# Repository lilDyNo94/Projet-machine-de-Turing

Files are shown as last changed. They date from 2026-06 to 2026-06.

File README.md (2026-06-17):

# 💻 Projet Électronique - Machine de Turing

**Auteurs :** Dylan Deshauteurs & Samba Niang  
**Encadrant :** M. Ronan Bocquillon 

---

## 📂 Arborescence du dépôt

Voici comment est structuré notre dépôt :

```text
.
├── Archive/                                  # Historique des projets des années précédentes
│   ├── Projet_2022_2023/
│   ├── Projet_2023_2024/
│   └── Projet_2024_2025/
│
├── Projet Elec - Machine de Turing/          # Dossier principal 
│   ├── Code/                                 # Fichiers sources et scripts annexes
│   ├── Datasheets/                           # Documentations techniques des composants électroniques
│   ├── KiCad/
│   │   └── Machine_de_turing/                # Fichiers de conception du routage PCB
│   ├── Ressources/                           # Images et ressources documentaires
│   ├── Schéma_élec/                          # Schémas structurels du circuit
│   ├── Diapo_Présentation_Machine_de_Turing_DESHAUTEURS_NIANG.pdf  # Support de présentation
│   └── Rapport_Machine_de_Turing_Deshauteurs_Niang.pdf             # Compte-rendu final du projet
│
├── lib_turing.c                              # Code source des fonctions de la Machine de Turing
├── lib_turing.h                              # Fichier d'en-tête (prototypes et structures)
├── main.c                                    # Programme principal (logique algorithmique)
└── README.md

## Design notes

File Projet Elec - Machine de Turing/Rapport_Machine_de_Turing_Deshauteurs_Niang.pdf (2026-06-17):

# P R O J E T E L E C T R O N I Q U E

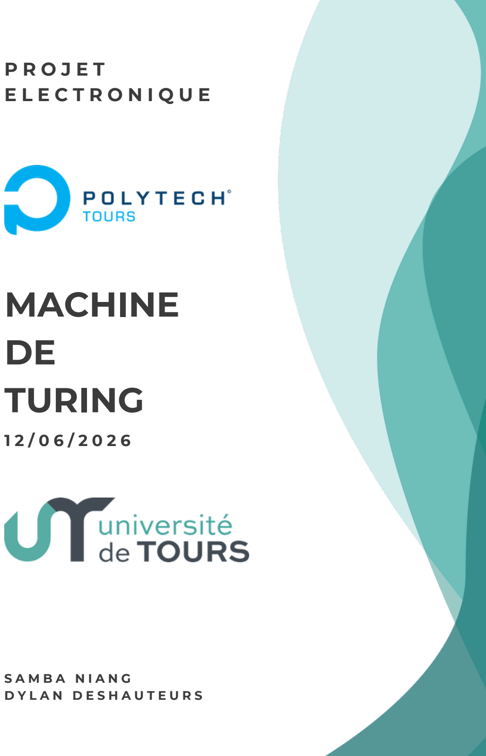
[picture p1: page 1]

# MACHINE

DE

# TURING

## D Y L A N D E S H A U T E U R S

1 2 / 0 6 / 2 0 2 6

## S A M B A N I A N G

SAMBA NIANG & DYLAN DESHAUTEURS | 0

## Sommaire

## I. Introduction

### Fondements Historiques

En 1936, le mathématicien britannique Alan Turing pose la pierre angulaire de l’informatique moderne avec son article « On Computable Numbers ». Loin des préoccupations matérielles de l'époque, Turing mène une réflexion de logique pure pour définir l'essence même du calcul.

Il conçoit alors une machine universelle théorique : un concept révolutionnaire capable d’exécuter n’importe quel processus logique, pourvu qu’il soit programmable.

Cette intuition théorique trouve son application concrète dès le déclenchement de la Seconde Guerre mondiale. Turing met ses concepts au service du décryptage pour briser les codes de la machine allemande Enigma.

### La Machine de Turing Universelle (MTU)

Le concept de Turing repose se compose de quatre éléments :

- Le Ruban : Une mémoire potentiellement infinie divisée en cases, chacune contenant un symbole.
- La Tête de Lecture/Écriture : Un dispositif capable de lire le symbole d'une case, d'en écrire un nouveau et de se déplacer vers la gauche ou la droite.
- Le Registre d'État : Il stocke l'état interne de la machine à un instant T.
- La Table de Transition : Il constitue le programme de la machine. Elle définit les règles d'interaction entre les trois composants précédents.

Le fonctionnement repose sur une table de transition. Pour chaque configuration (État actuel, Symbole lu), la machine exécute une action selon une règle stricte :

1. Écrire un nouveau symbole dans la case.
2. Changer l'état interne de la machine.
3. Déplacer la tête de lecture (Gauche/Droite/Immobile).

Exemple de transition : Si la machine est à l'état "E1" et lit "0", elle écrit "1", passe à l'état "E2" et se déplace vers la droite.

## II. Contexte Académique & états des lieux

Dans le cadre du cursus Informatique et Systèmes Intelligents Embarqués (ISIE), ce projet vise à transcrire les concepts abstraits de Turing en une réalisation concrète, aboutissant à la création d'une Machine de Turing Électronique.

### Continuité pédagogique

Cinquième équipe à relever ce défi, notre mission s'inscrit dans une véritable continuité pédagogique. L'enjeu est de consolider les acquis des groupes précédents pour aboutir à une version finale aboutie et stabilisée. Pour ce faire, notre développement s'appuie principalement sur l'architecture de ALLEGRE-COMMINGES Clément et BROUARD Romain, tout en intégrant les optimisations apportées par l'équipe de BOLARD Yassine et MANSO Alexis.

### Synthèse des travaux antérieurs

Le développement du projet a suivi une courbe d'apprentissage rigoureuse, partant de la conception théorique vers la mise en œuvre technique. Les premières recherches des groupes précédents ont permis de poser un socle fonctionnel solide.

L'effort s'est porté sur la production du firmware et l'assemblage des premiers composants. Toutefois, la réalisation finale a été freinée par des aléas matériels notamment des défaillances sur le ruban LED et par la complexité de l'intégration globale.

Ce passif technique nous permet aujourd'hui d'identifier précisément les points critiques, tant sur la fiabilité des composants que sur la gestion du temps, pour mener à bien l'achèvement de la maquette physique.

À notre arrivée, nous héritons d'une analyse théorique solide. Le projet se trouvait toutefois inachevé. Notre mission est d'agir comme intégrateur final : diagnostiquer les défaillances matérielles, corriger les erreurs de conception électronique et finaliser l'assemblage pour livrer une maquette 100% opérationnelle.

## III. Objectifs du Projet (Cahier des charges)

L’objectif principal est la conception et la réalisation d’un prototype physique fonctionnel d'une Machine de Turing Électronique, capable d'exécuter des processus logiques programmables.

### Phase 1 : Étude Théorique et Formalisation

L'enjeu est de maîtriser les fondements logiques avant toute implémentation technique :

1. Définir les principes de la machine de Turing et son architecture logique (Ruban, Tête, Table de transition).
2. Étudier et formaliser les algorithmes de calcul associés.
3. Présenter et expliciter un cas d'usage simple (exemple : incrémentation binaire) pour valider la compréhension du modèle.

### Phase 2 : Audit et Reprise de l'Existant

Afin de capitaliser sur les travaux des années précédentes, cette phase de "rétro-ingénierie" est cruciale :

1. Étudier les rapports existants pour en extraire les solutions les plus robustes.
2. Fixer l'architecture cible
3. Établir la nomenclature des composants et lancer les commandes.

### Phase 3 : Développement et Intégration Matérielle

Cette étape constitue le cœur technique de la réalisation :

1. Valider les schémas électroniques via des tests sur platine d'essai (Breadboard).
2. Adapter et implémenter le firmware en veillant à la stricte correspondance entre l'algorithme théorique et le déroulement du code.
3. Vérifier la fiabilité des cycles de lecture/écriture et des déplacements d'états.

### Phase bonus : Packaging et Conception CAO

Afin d'aboutir à un produit fini et professionnel :

1. Réaliser un circuit imprimé (PCB).
2. Concevoir et fabriquer un boîtier pour protéger l’électronique.

La planification complète de ces différentes étapes est synthétisée au sein d'une feuille de route globale, disponible en Annexe.

## IV. Analyse fonctionnelle

### Définition des besoins

Bête à corne

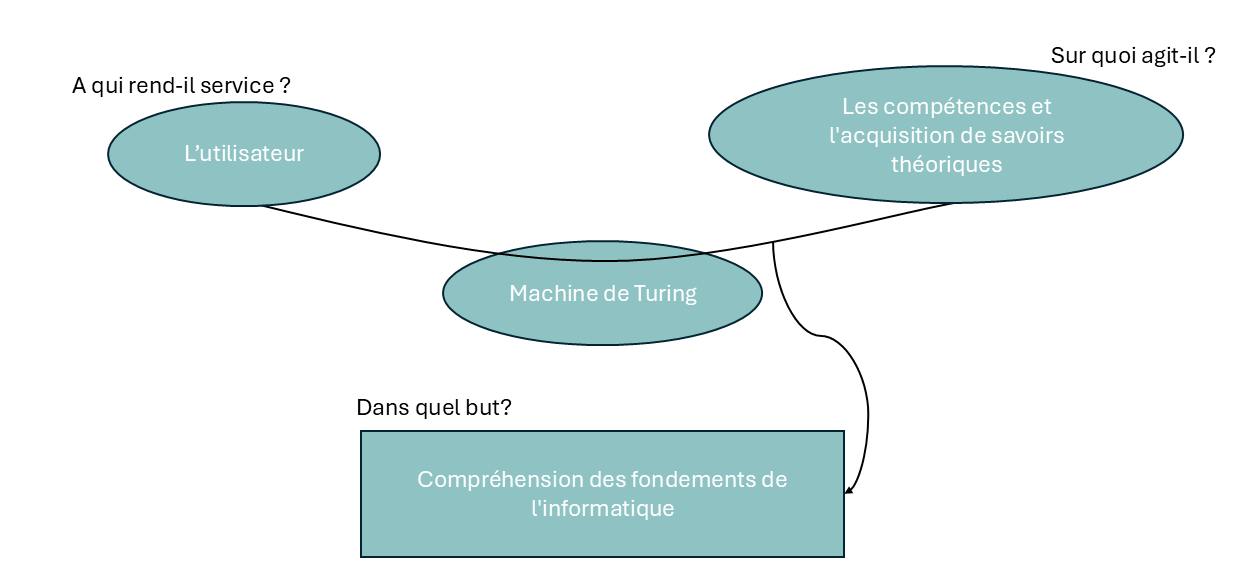
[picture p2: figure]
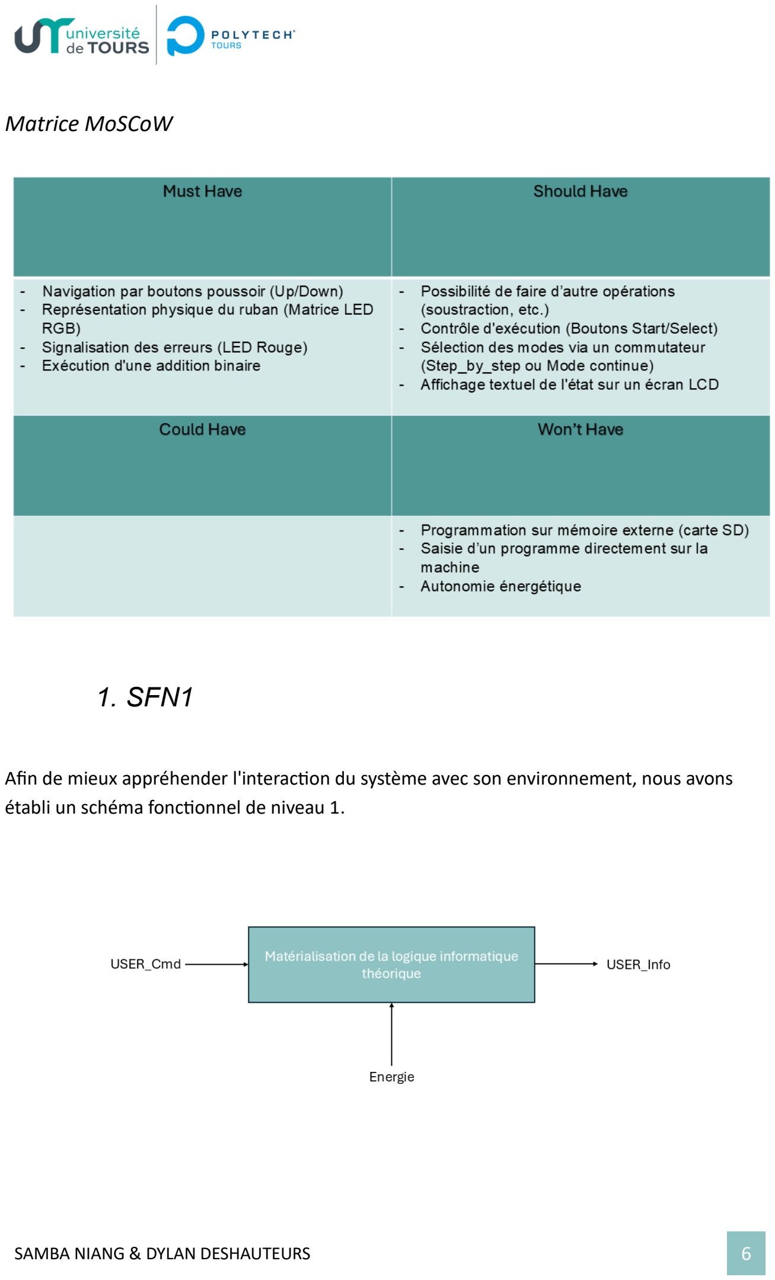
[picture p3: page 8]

Matrice MoSCoW

### 1. SFN1

Afin de mieux appréhender l'interaction du système avec son environnement, nous avons établi un schéma fonctionnel de niveau 1.

Les Commandes Utilisateur (boutons, commutateurs) pilotent la logique de la machine.

L'Énergie est fournie par le module d'alimentation stabilisé (3,3V/5V) pour permettre le fonctionnement des composants actifs.

Le bloc Traitement de la donnée est assuré par le microcontrôleur PIC24, qui exécute les règles de transition.

Le Résultat se traduit par la mise à jour visuelle du ruban LED et de l'écran LCD.

### 2. SF1D

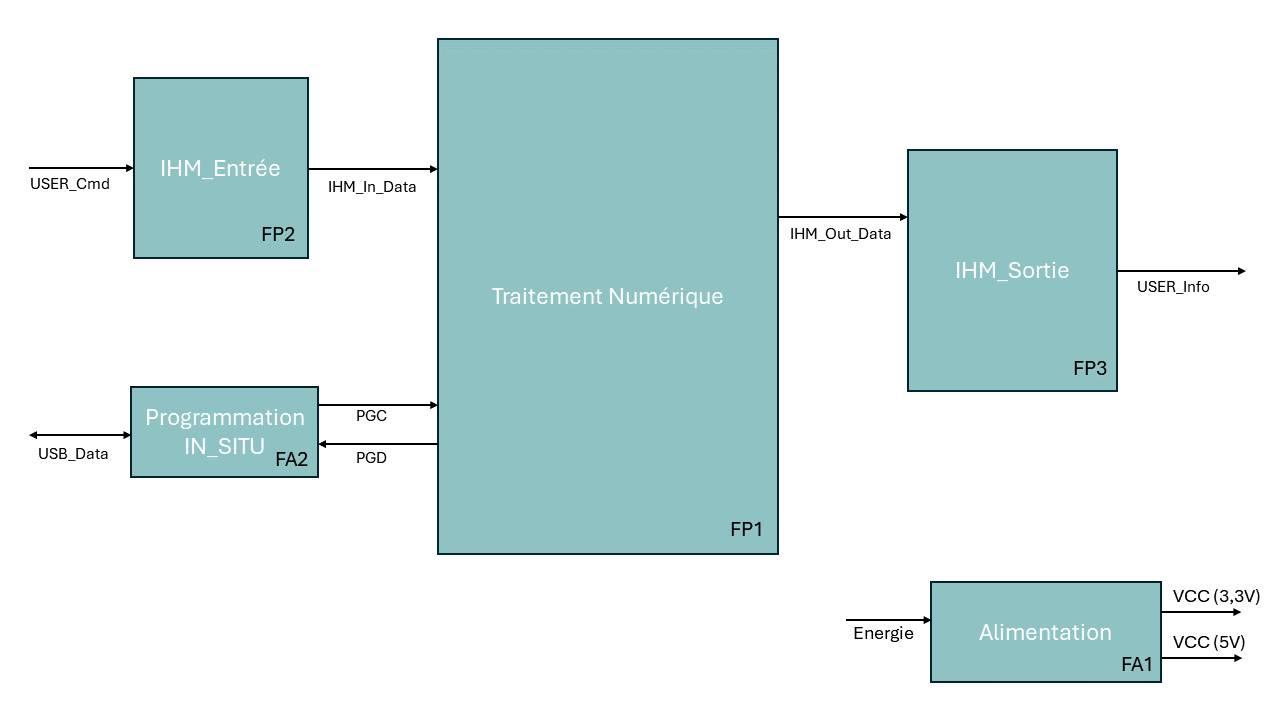
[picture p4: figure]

### 3. SF2D – FP2 (IHM_Entrée)

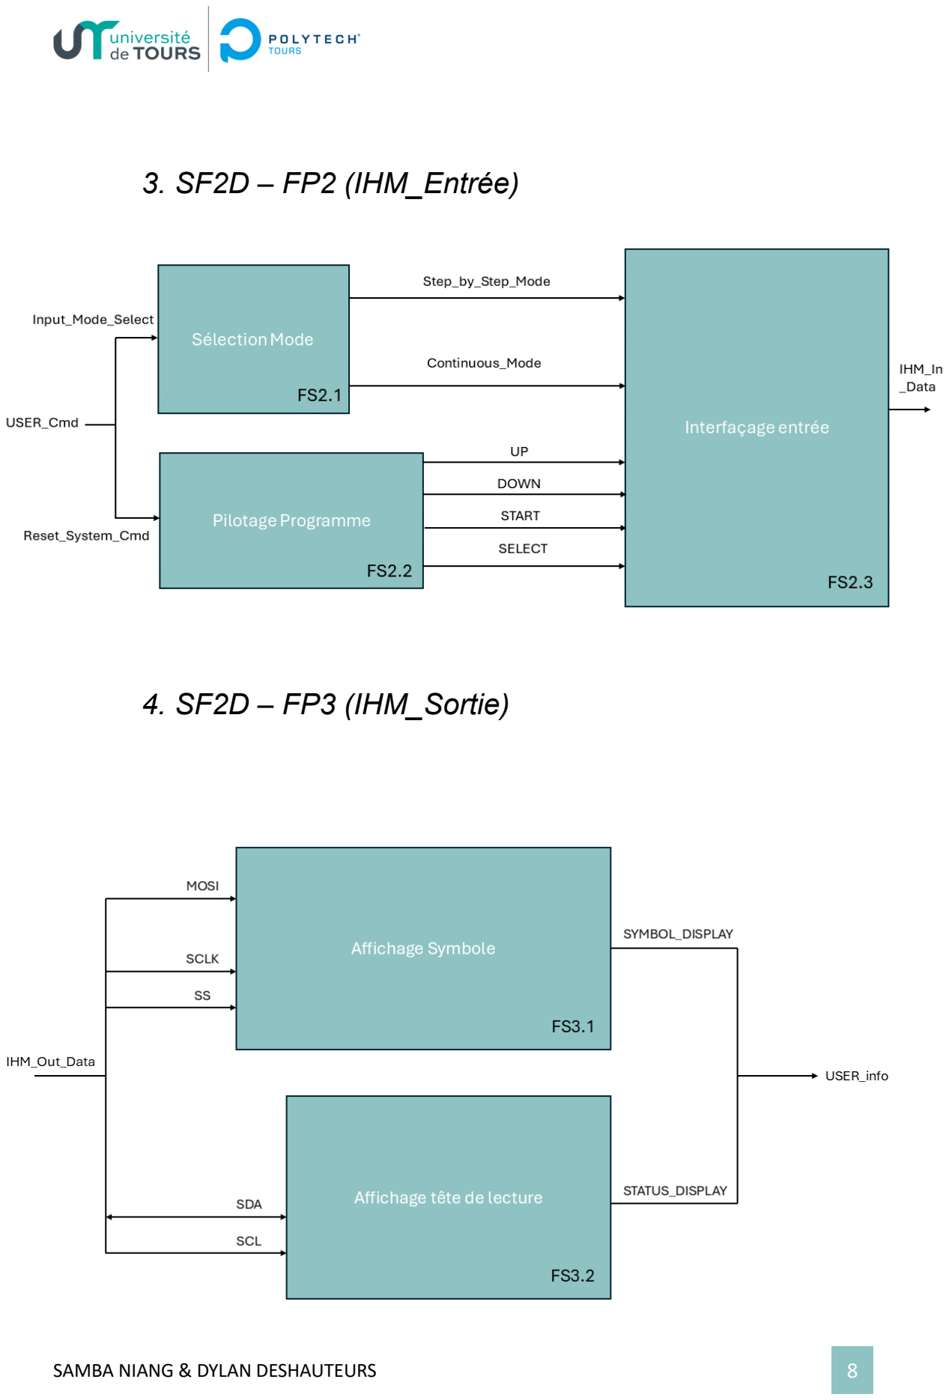
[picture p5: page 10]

### 4. SF2D – FP3 (IHM_Sortie)

### Spécifications des fonctions et de leurs signaux de communication

Fonction | FP1 | Traitements Numériques
Description / rôle | Réalise tous les traitements numériques nécessaires au bon fonctionnement du système
Signaux d'entrée | IHM_In_Data, IHM_Out_Data
Signaux de sortie | IHM_In_Ack, IHM_Out_St
Signaux E/S | Prog_Data
Fonction | FS 2.1 | Sélection mode
Description / rôle | Fonction qui sert à sélectionner le mode d’exécution pas à pas ou continu
Signaux d'entrée | Input_Mode_Select
Signaux de sortie | Step_by_Step_Mode, Continuous_Mode
Signaux E/S | NA
Fonction | FS 2.2 | Initialisation du programme
Description / rôle | Fonction qui permet d’initialiser les symboles et la tête de lecture
Signaux d'entrée | Reset_System_Cmd
Signaux de sortie | Start, Up, Down, Select
Signaux E/S | NA

Fonction | FS 2.3 | Interfaçage d’entrée
Description / rôle | Fonction qui sert de réceptacle et de commande du MCU
Signaux d'entrée | Start, Up, Down, Select, Step_by_Step_Mode, Continuous_Mode
Signaux de sortie | SCL
Signaux E/S | SDA
Fonction | FS 3.1 | Affichage Symbole
Description / rôle | Fonction réalisant l’affichage des symboles
Signaux d'entrée | MOSI, SCLK, SS
Signaux de sortie | MISO, Symbol_Display
Signaux E/S | NA
Fonction | FS 3.2 | Affichage de tête de lecture
Description / rôle | Fonction réalisant l’affichage de la tête de lecture
Signaux d'entrée | MOSI, SCLK, SS
Signaux de sortie | MISO, Status_Display
Signaux E/S | NA

Fonction | FA 1 | Alimentation
Description / rôle | Fonction qui alimente le système en électricité
Signaux d'entrée | Energie
Signaux de sortie | VCC
Signaux E/S | NA
Fonction | FA 2 | Programmation In Situ
Description / rôle | Fonction permettant de charger le programme dans le MCU
Signaux d'entrée | NA
Signaux de sortie | NA
Signaux E/S | USB_Data, Prog_Data

Ce tableau détaille l'ensemble des caractéristiques physiques, électriques et logiques de tous les signaux du système.

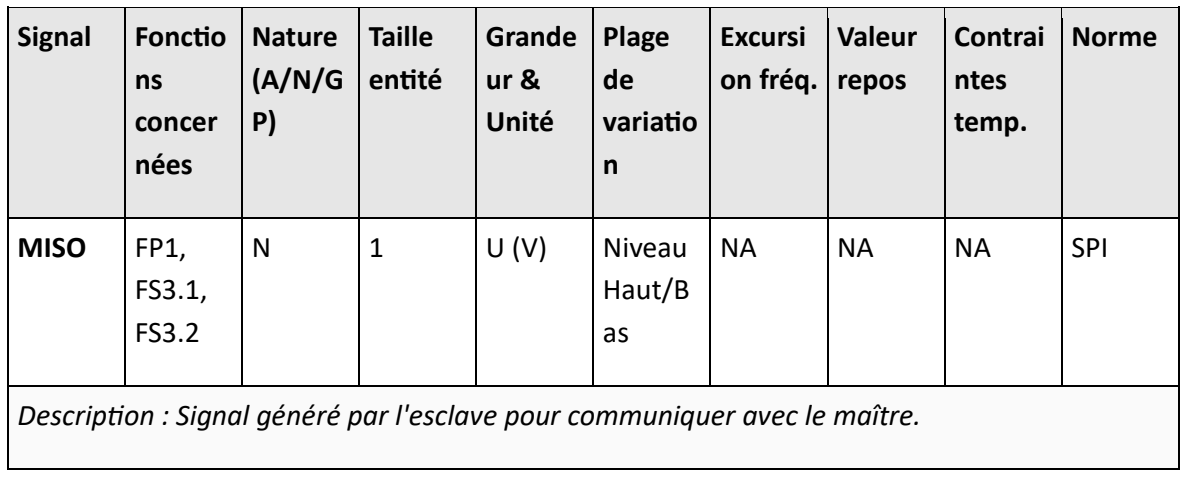
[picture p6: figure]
Signal; Fonctio; ns concer nées; Nature (A/N/G P); Taille entité; Grande ur & Unité; Plage de variatio n; Excursi on fréq.; Valeur repos; Contrai ntes temp.; Norme; MISO; Niveau; Haut/B as; SPI

Description : Signal généré par l'esclave pour communiquer avec le maître.

Signal Fonctio ns concer nées

Nature
(A/N/G
P)

Taille
entité

Grande
ur &
Unité

Plage
de
variatio
n

Excursi
on fréq.

Valeur
repos

Contrai
ntes
temp.

Norme

MOSI FP1,
FS3.1,
FS3.2
N | 1 | U (V) | Niveau
Haut/B
as
NA | NA | NA | SPI

Description : Signal généré par le maître pour communiquer avec l'esclave.

SCLK FP1,
FS3.1,
FS3.2
N | 1 | U (V) | Niveau
Haut/B
as
NA | NA | NA | SPI

Description : Signal de transmission de l'horloge par le maître.

SS FP1,
FS3.1,
FS3.2
N | 1 | U (V) | Niveau
Haut/B
as
NA | NA | NA | SPI

Description : Signal de sélection de l'esclave par le maître.

SDA FP1,
FS2.3
N | 1 | U (V) | Niveau
Haut/B
as
NA | 1 | NA | I2C

Description : Signal de transmission de données.

SCL FP1,
FS2.3
N | 1 | U (V) | Niveau
Haut/B
as
NA | 1 | NA | I2C

Description : Signal de transmission de l'horloge.

User_C
md

FS2.1,
FS2.2
GP | NA | U (V) | NA | NA | NA | NA | NA

Description : Action d'appui des boutons par l'utilisateur.

Signal Fonctio ns concer nées

Nature
(A/N/G
P)

Taille
entité

Grande
ur &
Unité

Plage
de
variatio
n

Excursi
on fréq.

Valeur
repos

Contrai
ntes
temp.

Norme

Input_
Mode_
Select
FS2.1 | N | 1 | U (V) | Niveau Haut/B as
NA | NA | NA | NA

Description : Image du mode : niveau bas = pas à pas, niveau haut = continu.

Reset_S
ystem_
Cmd
FS2.2 | N | 1 | U (V) | Niveau Haut/B as
NA | NA | NA | NA

Description : Image de l'appui sur le bouton d'initialisation.

Start | FS2.2 | N | 1 | U (V) | Niveau Haut/B as
NA | NA | NA | NA

Description : Image de l'appui sur le bouton de lancement.

Energie | FA1 | A | 1 | U (V) | 230 V CA
50 Hz | NA | NA | NA

Description : Courant alternatif monophasé (Réseau électrique).

VCC | FA1 | A | 1 | U (V) | 5 V ou 3.3 V CC
NA | NA | NA | NA

Description : Énergie continue dont le MCU a besoin pour fonctionner.

ISCP FP1,
FA2
N | 1 | NA | Niveau
Haut/B
as
NA | 0 | NA | NA

Description : Signal de transmission des données pour la programmation in situ.

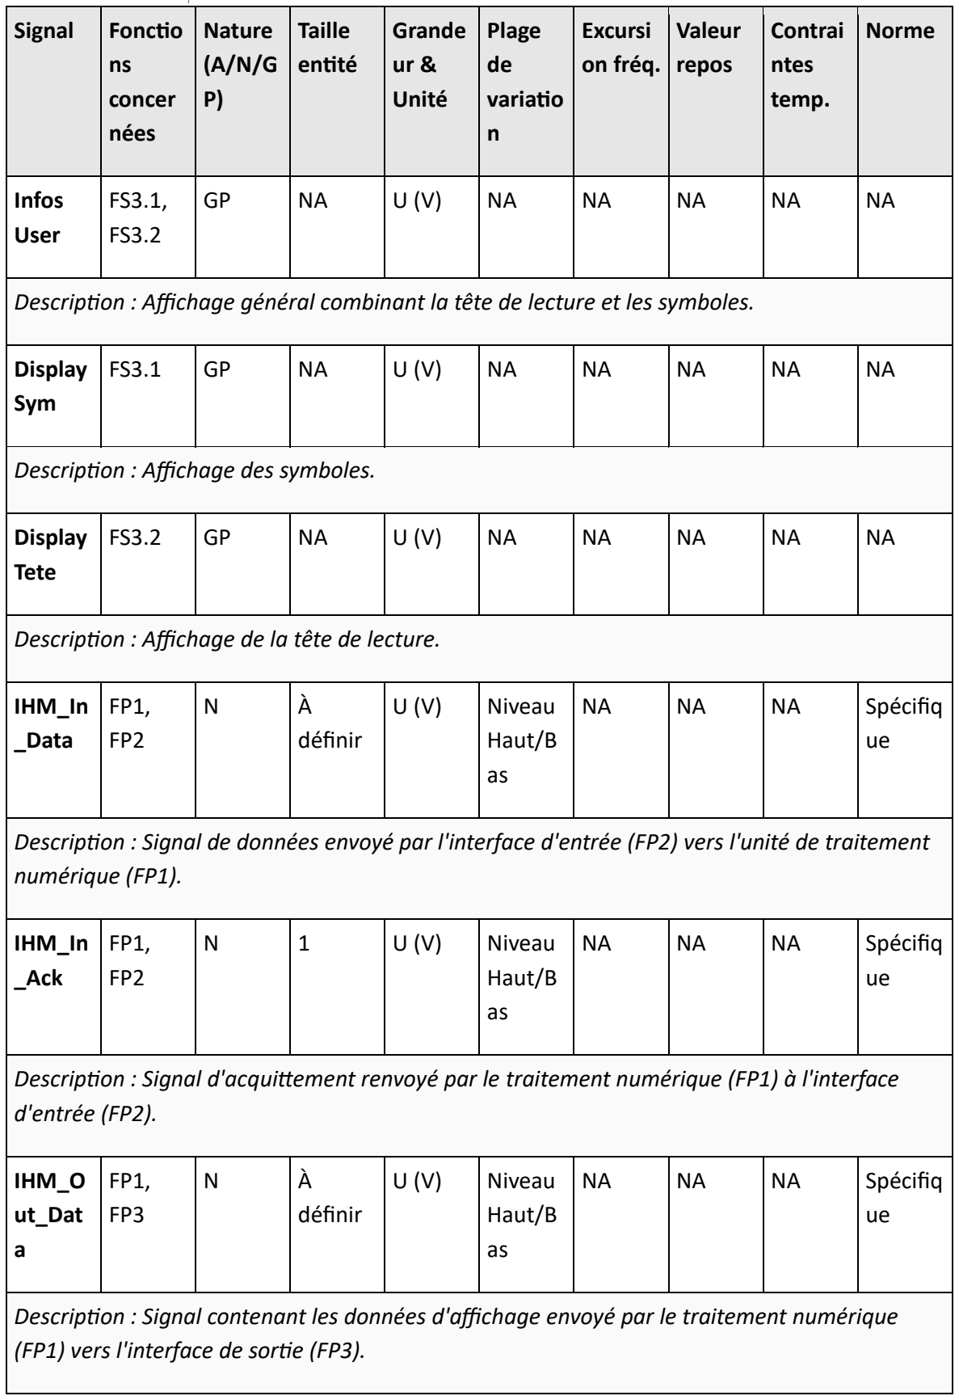
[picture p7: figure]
Signal; Fonctio; ns concer nées; Nature (A/N/G P); Taille entité; Grande ur & Unité; Plage de variatio n; Excursi on fréq.; Valeur repos; Contrai ntes temp.; Norme; Infos User; Display Sym; Description : Affichage des symboles.; Display Tete; IHM_In _Data; définir; Niveau; Haut/B as; Spécifiq; numérique (FP1).; IHM_In _Ack; d'entrée (FP2).; IHM_O ut_Dat a; (FP1) vers l'interface de sortie (FP3).

Description : Affichage général combinant la tête de lecture et les symboles.

Description : Affichage de la tête de lecture.

Description : Signal de données envoyé par l'interface d'entrée (FP2) vers l'unité de traitement

Description : Signal d'acquittement renvoyé par le traitement numérique (FP1) à l'interface

Description : Signal contenant les données d'affichage envoyé par le traitement numérique

Signal Fonctio ns concer nées

Nature
(A/N/G
P)

Taille
entité

Grande
ur &
Unité

Plage
de
variatio
n

Excursi
on fréq.

Valeur
repos

Contrai
ntes
temp.

Norme

IHM_O
ut_St

FP1,
FP3
N | À
définir

U (V) Niveau
Haut/B
as
NA | NA | NA | Spécifiq ue

Description : Signal d'état ou de contrôle renvoyé par l'interface d'affichage (FP3) vers le traitement numérique (FP1).

Prog_D
ata

FP1,
FA2
N | À
définir

U (V) Niveau
Haut/B
as
NA | NA | NA | Spécifiq ue

Description : Signal bidirectionnel d'échange de données de programmation entre le module In Situ (FA2) et le MCU (FP1).

USB_D
ata
FA2 | N | À
définir

U (V) Spécifiq
ue USB

Horloge
USB
NA | NA | USB

Description : Liaison de données bidirectionnelle externe permettant de charger le programme via l'interface USB.

Step_b
y_Step
_Mode

FS2.1,
FS2.3
N | 1 | U (V) | Niveau
Haut/B
as
NA | NA | NA | NA

Description : Signal activant le mode d'exécution pas à pas envoyé à l'interfaçage d'entrée.

Continu
ous_M
ode

FS2.1,
FS2.3
N | 1 | U (V) | Niveau
Haut/B
as
NA | NA | NA | NA

Description : Signal activant le mode d'exécution continu envoyé à l'interfaçage d'entrée.

Up FS2.2,
FS2.3
N | 1 | U (V) | Niveau
Haut/B
as
NA | NA | NA | NA

Signal Fonctio ns concer nées

Nature
(A/N/G
P)

Taille
entité

Grande
ur &
Unité

Plage
de
variatio
n

Excursi
on fréq.

Valeur
repos

Contrai
ntes
temp.

Norme

Description : Signal d'incrémentation ou de déplacement vers le haut pour la configuration du système.

Down FS2.2,
FS2.3
N | 1 | U (V) | Niveau
Haut/B
as
NA | NA | NA | NA

Description : Signal de décrémentation ou de déplacement vers le bas pour la configuration du système.

Select FS2.2,
FS2.3
N | 1 | U (V) | Niveau
Haut/B
as
NA | NA | NA | NA

Description : Signal de sélection ou de validation d'une option envoyé à l'interfaçage d'entrée.

SYMBO
L_DISPL
AY
FS3.1 | GP | À
définir

U (V) Spécifiq
ue
Matrice
NA | NA | NA | Matrice RGB

Description : Signal physique de commande envoyé à la matrice de LED (RGB_MATRIX) pour afficher les symboles.

STATUS
_DISPL
AY
FS3.2 | GP | À
définir

U (V) Spécifiq
ue
Écran
NA | NA | NA | Écran LCD

Description : Signal physique de commande envoyé à l'écran LCD (LCD_SCREEN) pour afficher l'état de la tête de lecture.

## V. Conception matérielle (Hardware)

### Choix des composants

Par rapport aux objectifs initiaux et aux travaux des promotions précédentes, notre équipe a pris la décision de retirer plusieurs éléments périphériques, notamment le module de stockage externe par carte SD ainsi que les fonctions de programmation directe des tables de transition sur la machine.

Ce choix de simplification est dicté par une volonté de fiabiliser le cœur de calcul et de stabiliser les communications sur les bus I2C et SPI. En nous concentrant sur les fonctionnalités essentielles, nous avons pu nous assurer que l'unité centrale dispose de toutes les ressources nécessaires en mémoire Flash interne pour exécuter les algorithmes de Turing de manière robuste. Ce recentrage technique nous permet ainsi de garantir une maquette fonctionnelle privilégiant la qualité de l'exécution arithmétique à la multiplication d'options secondaires.

Pour transformer le modèle théorique en une maquette physique, nous avons sélectionné des composants répondant aux contraintes de robustesse et de simplicité d'interfaçage

Microcontrôleur PIC24FJ64GA002

Le choix s'est porté sur ce microcontrôleur 16 bits pour plusieurs raisons stratégiques :

- Capacité de calcul suffisante pour gérer les tables de transition et les opérations arithmétiques (addition, soustraction, ect).
- La mémoire Flash interne est en accord avec notre choix de supprimer la carte SD, sa mémoire interne permet de stocker directement les algorithmes.
- Il gère nativement les protocoles I2C pour le LCD et SPI pour la matrice LED

Interface Homme-Machine (IHM)

L'interface est composée de :

- 4 Boutons Poussoirs qui assurent la navigation (Up/Down) et le contrôle (Start/Select).
- 1 Commutateur à levier dédié à la sélection matérielle du mode (Continu ou Pas-à-pas). Ce choix permet un changement d'état franc.
- Une LED rouge pour signaler les erreurs système.

Dispositifs d'Affichage

- Écran LCD (NHD-C0220BIZ) :

Sa fonction principale est l'affichage du menu, de l'état interne de la machine et de la table de transition. Il utilise une interface par bus I2C afin de minimiser le nombre de fils nécessaires sur le PIC24.

- Matrice de LEDs RGB :

La matrice de LEDs RGB assure la représentation physique du Ruban de Turing. Dans cette configuration, chaque LED simule une case du ruban et change de couleur selon le symbole stocké. L'interface utilise le bus SPI pour garantir une vitesse de rafraîchissement élevée, ce qui est particulièrement crucial lors des calculs effectués en mode continu.

### Schéma structurel

Le schéma ci-dessous présente l'unité de traitement architecturée autour du microcontrôleur PIC24FJ64GA002. Il met en évidence une distribution sectorisée et optimisée des entrées/sorties : le protocole I2C pilote l'affichage textuel, le bus SPI (remappé sur les broches inférieures) gère la matrice RGB du ruban, tandis que les boutons et le commutateur exploitent les lignes d'interruption matériel CN pour maximiser la réactivité du système.

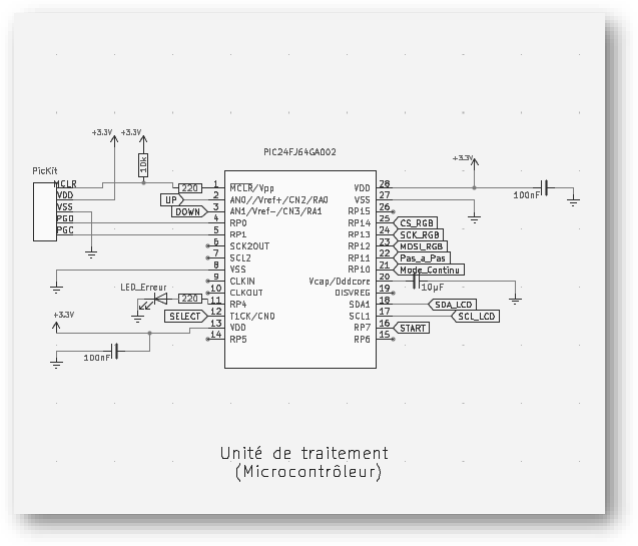
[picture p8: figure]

Cette section du schéma ci-dessous met en évidence la sectorisation des interfaces de sortie de la machine. L'afficheur textuel LCD utilise le bus I2C (3,3V) avec des lignes de rappel à un niveau haut de 10kΩ, limitant l'utilisation des broches du microcontrôleur. En parallèle, le contrôleur de la matrice LED RGB (le ruban) est piloté via un bus SPI dédié. Ce choix du SPI synchrone garantit le débit de données nécessaire à la fluidité visuelle du ruban, tout en adaptant les niveaux de puissance puisque la matrice fonctionne sous une alimentation distincte de 5V.

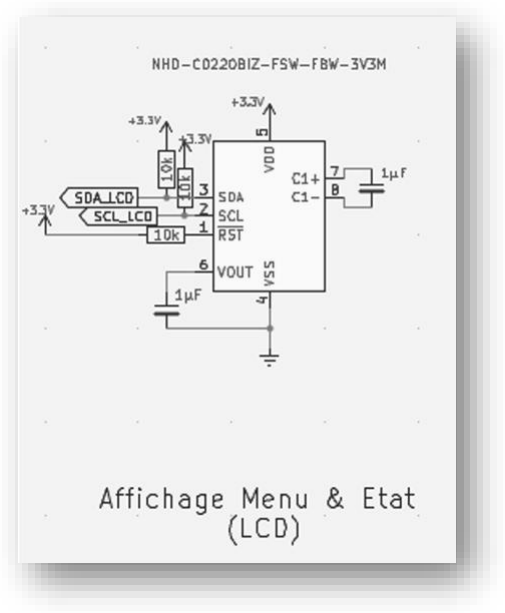
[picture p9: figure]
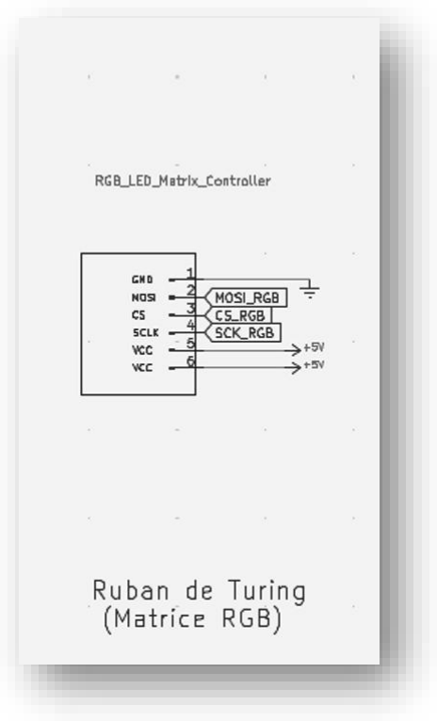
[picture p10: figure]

Ce schéma ci-dessous détaille l'implémentation matérielle de l'interface homme-machine d'entrée. Les quatre boutons-poussoirs dédiés au contrôle de l'application intègrent des résistances de pull-up de 10kΩ maintenant un niveau logique haut par défaut. À l'inverse, le commutateur à levier exploite deux résistances de pull-down de 10kΩ afin de basculer de manière stable entre les lignes de commande « Pas_a_Pas » et « Mode_Continue ». Cette sectorisation électrique, directement reliée aux entrées de notification de changement (CN) du microcontrôleur, élimine les risques de rebonds logiciels critiques lors de l'exécution des tables de transition.

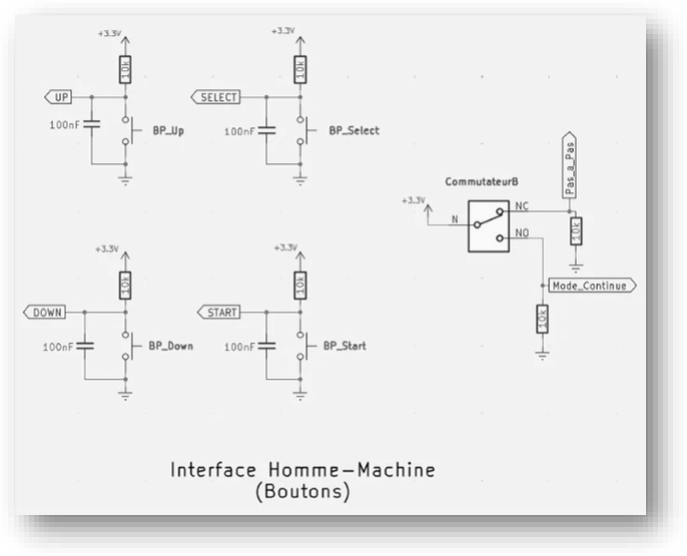
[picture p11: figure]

### Conception du circuit imprimé (PCB)

À l'issue de la phase de validation matérielle sur platine d'essai, nous avons procédé au routage d'un circuit imprimé (PCB) dédié. L'objectif principal de cette étape est de fiabiliser les connexions électriques, d'éliminer les risques de faux contacts inhérents au prototypage, et de compacter l'électronique en vue de son intégration dans le boîtier final.

Le design de cette carte a été pensé pour centraliser l'unité de traitement, la distribution d'énergie, ainsi que le routage optimisé les bus de communication (SPI et I2C) vers les périphériques externes (matrice LED et écran LCD).

Les figures ci-dessous présente le rendu de notre conception avant fabrication :

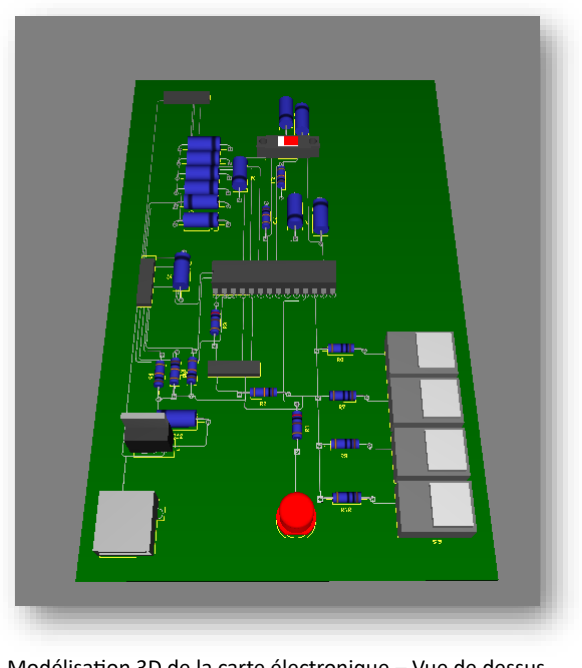
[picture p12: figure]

Modélisation 3D de la carte électronique – Vue de dessus

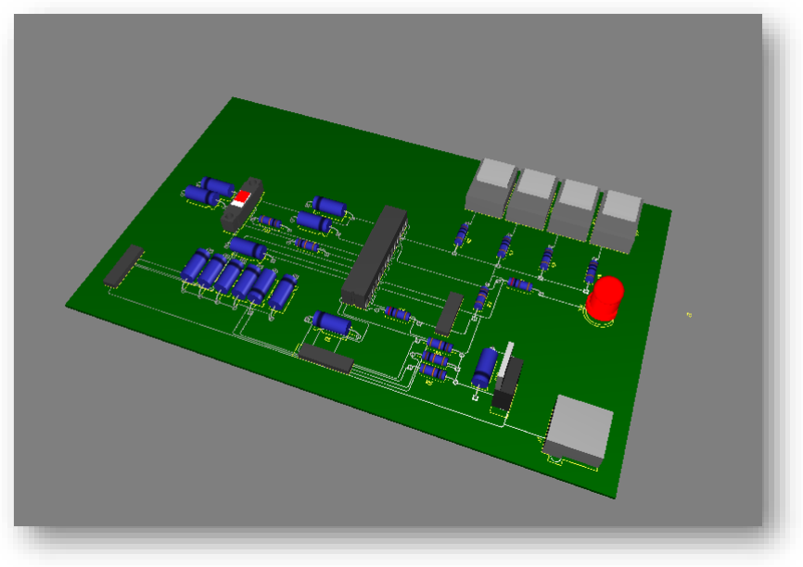
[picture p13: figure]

## VI. Conception logicielle et algorithmique (Software)

### Logique de traitement

Afin de valider le fonctionnement logique de notre Machine de Turing, nous avons implémenté un algorithme d'addition de deux nombres binaires (voir ci-dessous). Cet algorithme repose sur une machine à états finis de l'état 1 à 6 permettant de parcourir la bande, de décrémenter le second opérande et d'incrémenter le premier par propagations successives de retenues. La table des transitions complète, détaillant les états, les lectures de couleurs (Rouge pour 0, Vert pour 1, Vide pour le séparateur) et les déplacements de la tête de lecture, est disponible en Annexe de ce rapport.

Modélisation 3D de la carte électronique – Vue isométrique void addition(Etat *Etats) {

// ETAT 0 : Chercher la fin de la bande tout a droite
Etats[0].final = 0;
action_create(&Etats[0].transition[1], 1, droite, 0); // Si 1 -> on avance action_create(&Etats[0].transition[2], 2, droite, 0); // Si 0 -> on avance action_create(&Etats[0].transition[0], 0, gauche, 1); // Si Blanc -> on recule et on passe a l'Etat 1

// ETAT 1 : Soustraire 1 au nombre B (Droite)
Etats[1].final = 0;
action_create(&Etats[1].transition[2], 1, gauche, 1); // Lit 0 (Rouge) -> Ecrit 1 (Vert), propage a gauche
action_create(&Etats[1].transition[1], 2, gauche, 2); // Lit 1 (Vert) -> Ecrit 0 (Rouge), fin de soustraction (Etat 2)
action_create(&Etats[1].transition[0], 0, rien, 6); // Lit Blanc -> B est vide ! On a fini l'addition (Etat 6)

// ETAT 2 : Voyager a gauche jusqu'au deuxieme nombre (A)
Etats[2].final = 0;
action_create(&Etats[2].transition[1], 1, gauche, 2); // Si 1 -> on recule action_create(&Etats[2].transition[2], 2, gauche, 2); // Si 0 -> on recule action_create(&Etats[2].transition[0], 0, gauche, 3); // Si Blanc (separateur) -> on passe le separateur (Etat 3)

// ETAT 3 : Ajouter 1 au nombre A (Gauche)
Etats[3].final = 0;
action_create(&Etats[3].transition[1], 2, gauche, 3); // Lit 1 (Vert) -> Ecrit 0 (Rouge), propage la retenue a gauche
action_create(&Etats[3].transition[2], 1, droite, 4); // Lit 0 (Rouge) -> Ecrit 1 (Vert), fin d'addition (Etat 4)
action_create(&Etats[3].transition[0], 1, droite, 4); // Lit Blanc (debordement) -> Ecrit 1 (Vert), fin d'addition (Etat 4)

// ETAT 4 : Voyager a droite jusqu'au separateur
Etats[4].final = 0;
action_create(&Etats[4].transition[1], 1, droite, 4); // Si 1 -> on avance action_create(&Etats[4].transition[2], 2, droite, 4); // Si 0 -> on avance action_create(&Etats[4].transition[0], 0, droite, 5); // Si Blanc (separateur) -> on passe le separateur (Etat 5)

// ETAT 5 : Voyager a droite jusqu'a la fin du nombre B
Etats[5].final = 0;
action_create(&Etats[5].transition[1], 1, droite, 5); // Si 1 -> on avance action_create(&Etats[5].transition[2], 2, droite, 5); // Si 0 -> on avance action_create(&Etats[5].transition[0], 0, gauche, 1); // Si Blanc (fin de bande) -> on recule et on boucle a l'Etat 1

// ETAT 6 : Etat final
Etats[6].final = 1; // La machine s'arrete ici !
}

### Modélisation algorithmique

Pour illustrer le comportement de l'algorithme implémenté dans le microcontrôleur, la figure ci-dessous modélise l'enchaînement des états sous forme de logigramme.

Le principe fondamental de cette machine à états repose sur l'évaluation et la modification des couleurs lues sur le ruban matriciel.

L'algorithme boucle sur une séquence spatiale stricte : la machine évalue la couleur actuelle (État 1) et l'inverse selon les règles de calcul, puis la tête de lecture se déplace vers la gauche (État 2) pour aller reporter la retenue (État 3). Une fois la couleur mise à jour, la tête repart vers la droite (États 4 et 5) pour traiter le symbole suivant.

Les écritures matérielles sur la matrice LED sont instantanées et ce cycle de balayage (gauche/droite) se répète inlassablement jusqu'à la détection d'une case vide (symbole O) lors de l'État 1, ce qui déclenche l'arrêt définitif de la machine (État 6).

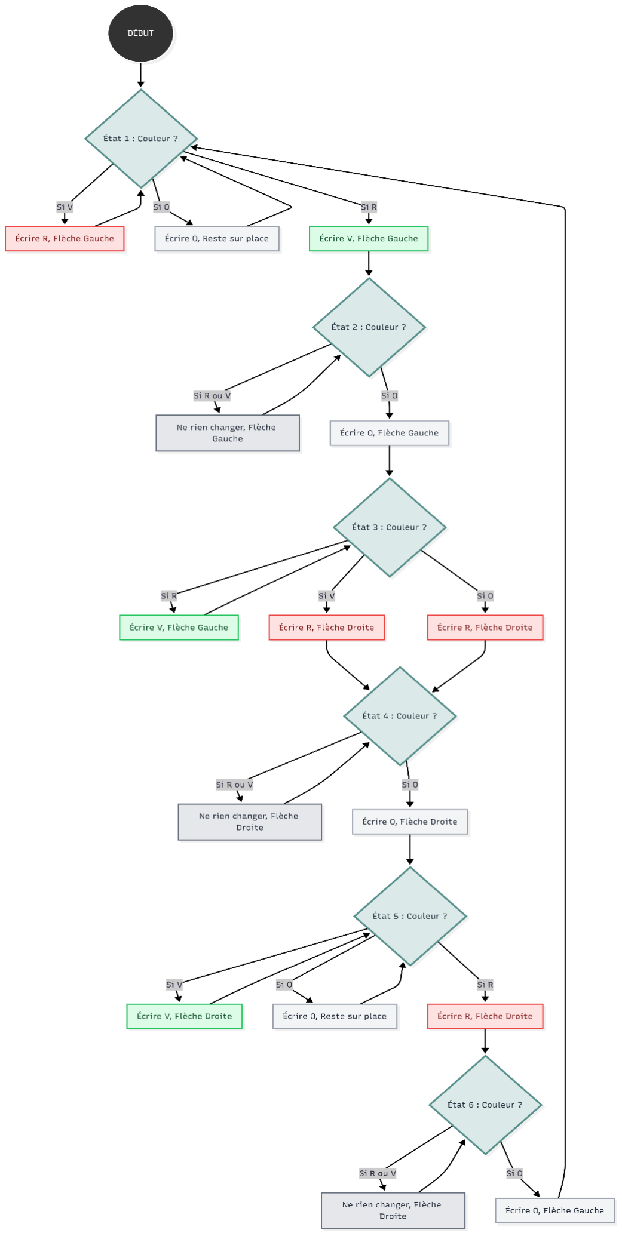
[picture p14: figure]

## VII. Intégration et Validation Expérimentale

### Protocoles de Test

Afin de garantir le fonctionnement fiable et robuste de la Machine de Turing, nous avons établi une campagne d'essais méthodique. L'objectif de cette phase était de valider physiquement et fonctionnellement chaque bloc de notre architecture avant leur assemblage final.

Elément Validé :

- Reconnaissance et programmation : Le microcontrôleur PIC24FJ64GA002 est correctement reconnu. La programmation est pleinement opérationnelle.
- Entrées numériques : Les entrées sont bien détectées par le programme, ce qui valide la partie matérielle pour les deux pins concernées (boutons poussoirs "UP" et "DOWN").
- Logique de calcul : Le programme lance correctement la procédure de calcul (addition) pour donner suite à l'action sur les boutons "START" et "SELECT".
- Gestion de la matrice (Ruban RGB) : La matrice est bien pilotée via le bus SPI, validant ainsi la gestion séquentielle des cases du ruban.
- Signalisation d'erreur : Le circuit de diagnostic matériel est opérationnel, la LED rouge d'erreur s'allume correctement via le code.

Elément non validé :

- Communication I2C (Écran LCD) : L'écran reste totalement inerte. On suspecte un défaut matériel.
- Bascule de mode (Commutateur) : Bien que le câblage soit validé et que le signal soit stable sur l'entrée lors du basculement, le test n’a pas été réalisé.

La fiche de test est disponible en Annexe.

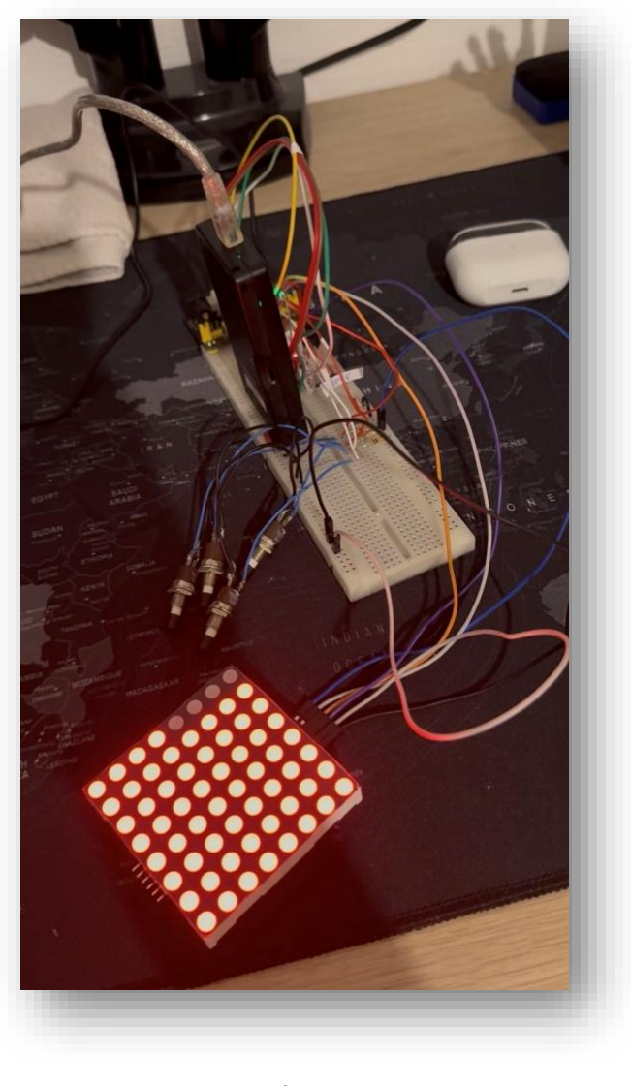
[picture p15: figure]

### Elaboration des codes de test unitaire & firmware final

Pour mener à bien nos protocoles de test, nous avons opté pour une approche de développement modulaire. Plutôt que de programmer l'ensemble du système d'un seul bloc, nous avons mis en place des codes de test unitaires pour chaque périphérique.

Prototypage sur platine d'essai validant le pilotage de la matrice LED par le microcontrôleur

Nos objectifs, à travers la mise en place de ces scripts de validation, étaient les suivants :

- Code de test des Interruptions (Entrées) : L'objectif était de configurer et de valider le module Change Notification (CN) du PIC24. Nous voulions nous assurer qu'une action physique de l'utilisateur déclenche instantanément une routine d'interruption logicielle, confirmant ainsi que le microcontrôleur n'a pas besoin de perdre du temps de calcul à scruter l'état des boutons.
- Code de test de l'Afficheur LCD : Le but était d'isoler la communication I2C. Le code mis en place visait uniquement à initialiser le bus, cibler l'adresse matérielle de l'écran, et afficher une chaîne de caractères simple (ex: "Test OK").
- Code de test de la Matrice RGB : Ce code répondait à un double objectif. Premièrement, valider le paramétrage logiciel du registre PPS (Peripheral Pin Select) permettant d'assigner les broches physiques aux signaux SPI. Deuxièmement, envoyer des séquences de couleurs pures (Rouge, Vert, Bleu) pour s'assurer de la synchronisation de l'horloge SPI (SCK) et de l'intégrité de la ligne de données (MOSI).
- Code de test de la LED d'état : L'objectif de ce script très court était de vérifier la bonne configuration des directions des ports et de confirmer que l'oscillateur principal du système fonctionnait à la fréquence attendue.

Ce n'est qu'une fois ces objectifs logiciels unitairement atteints que nous avons pu fusionner ces codes pour former le firmware complet de la machine.

L’ensemble du code est disponible en Annexe.

## Conclusion générale et perspectives

L'aboutissement de ce projet marque la transition réussie d'un modèle mathématique théorique vers un prototype matériel interactif. Notre mission initiale visait à stabiliser les travaux des promotions précédentes pour livrer une Machine de Turing électronique exploitable et fiable.

Si l'on se réfère à notre cahier des charges, l'objectif critique est rempli : l'ensemble des fonctionnalités critiques ont été implémentées avec succès. L'architecture matérielle est aujourd'hui stabilisée avec la conception et le routage finalisé d'un circuit imprimé (PCB), bien que ce dernier n'ait pas encore été envoyé en fabrication. Les communications avec les périphériques fonctionnent, et l'exécution du programme d'addition binaire valide le cœur logique du système.

Face aux impératifs d'intégration matérielle et temporelle, nous avons fait le choix de privilégier la fiabilité du système au détriment du nombre de fonctionnalités. De ce fait, les interfaces d'usage secondaires, telles que la commutation des modes d'exécution (pas-à-pas et continu) ainsi que l'affichage textuel sur l'écran LCD, n'ont pas encore été totalement finalisées.

Si le montage actuel prouve la viabilité du concept, il dessine également une feuille de route claire pour les futures itérations de la machine.

Le socle logique et l'architecture électronique étant validés, les développements futurs devront se concentrer sur l'achèvement de l'interface utilisateur et la finalisation matérielle de la machine. Nous suggérons d'orienter les futures itérations autour des axes suivants :

- Programmer l'affichage textuel sur l'écran LCD pour indiquer l'état courant. Traiter les interruptions matérielles pour rendre fonctionnelle la commutation entre le mode d'exécution continu et le mode pas-à-pas.
- Créer une routine logicielle permettant d'entrer de nouvelles tables de transition directement via les boutons. Cela élargira les opérations possibles (soustraction, multiplication) sans nécessiter de reprogrammer le microcontrôleur.
- Lancer la fabrication physique du circuit imprimé (PCB). Modéliser et imprimer un boîtier en 3D pour protéger l'électronique.

## Remerciement

Nous tenons à exprimer notre gratitude à l’ensemble des personnes qui ont contribué au bon déroulement de ce projet.

Nos remerciements s’adressent tout d’abord à Monsieur Bocquillon, notre tuteur, pour sa confiance, son suivi et ses conseils tout au long de la réalisation de ce travail. Son accompagnement direct a été un élément moteur dans l'atteinte de nos objectifs.

Nous saluons également l'implication de Monsieur Rolland pour son expertise technique, sa disponibilité et ses orientations méthodologiques indispensables lors des phases clés de conception du système.

Enfin, nous tenons à remercier tout particulièrement Monsieur Clément ALLEGRE-COMMINGES et Monsieur Romain BROUARD. Leur intervention lors de la réunion de cadrage initiale a été déterminante pour définir les contours du projet, comprendre les attentes pédagogiques du système et poser les bases de notre réflexion globale.

## Annexe & bibliographie

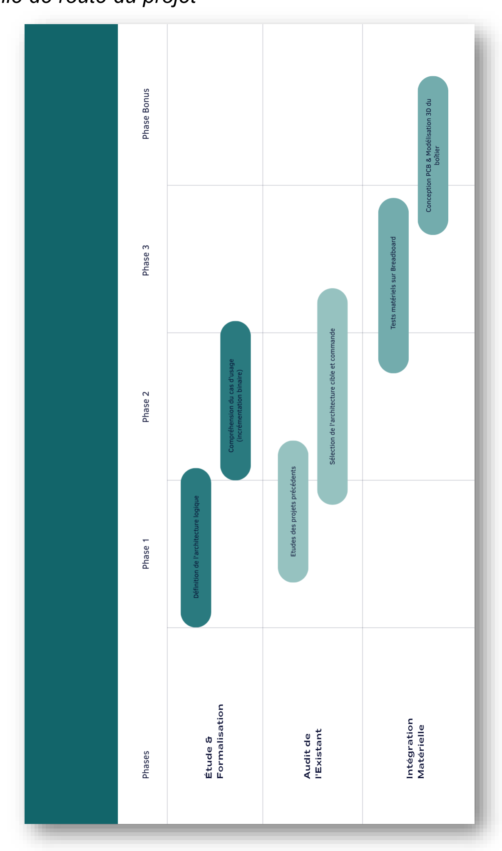
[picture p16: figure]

### Feuille de route du projet

### Algorithme d’addition de deux nombres binaires

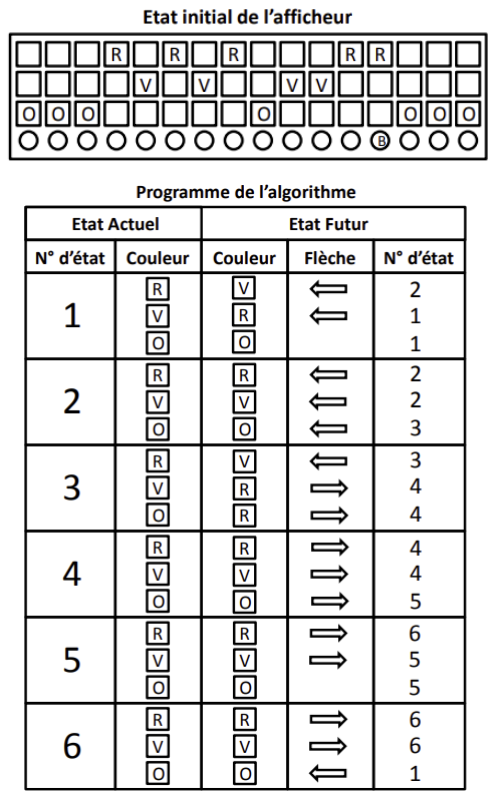
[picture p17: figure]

### Fiche de test

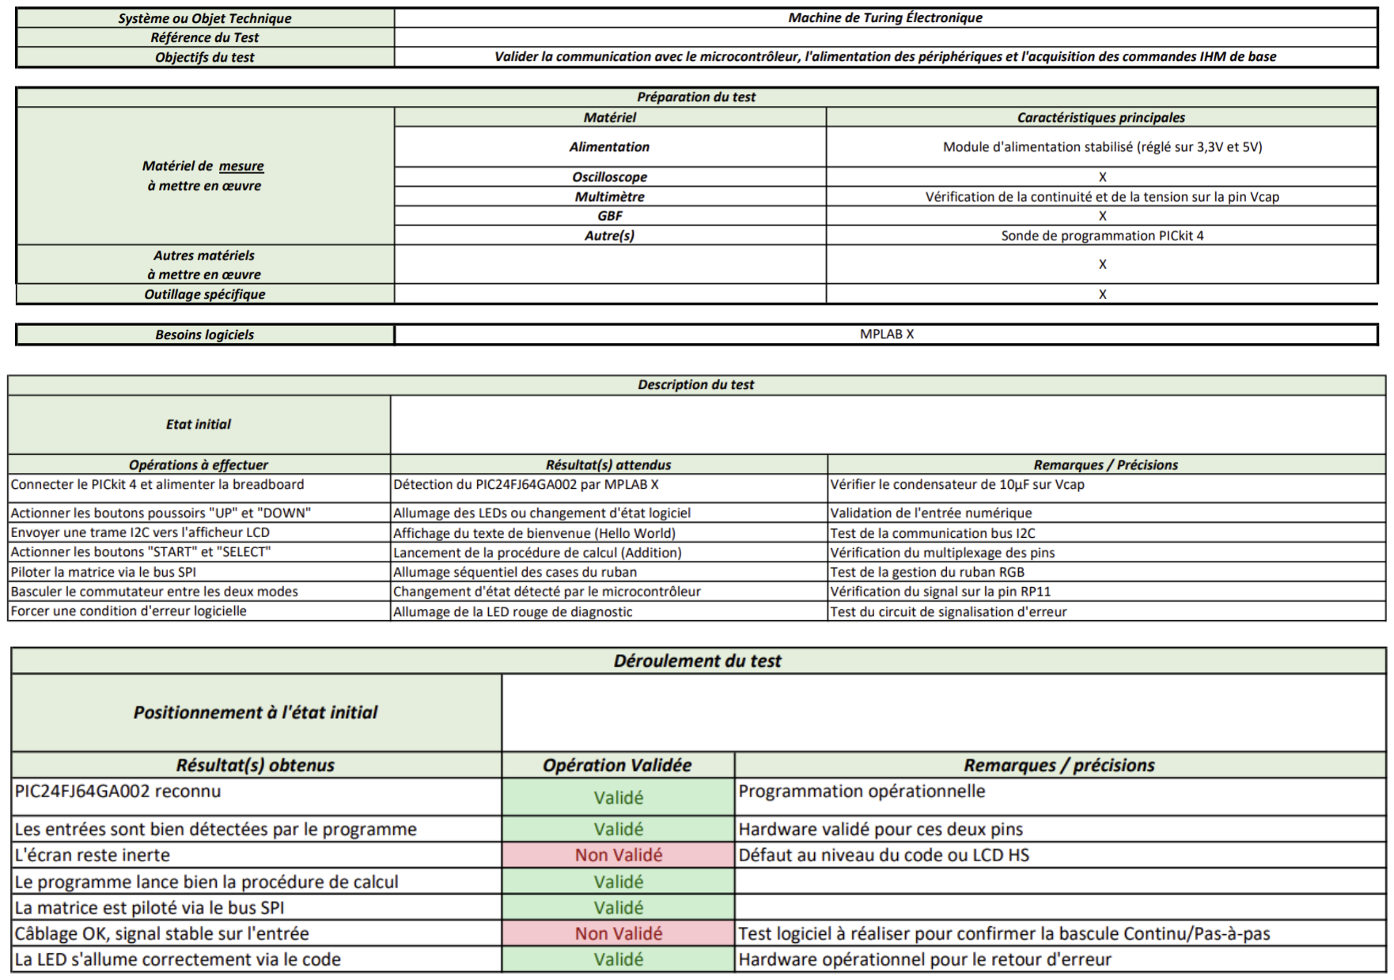
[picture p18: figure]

### Firmware de la machine de Turing

Disponible via ce lien GitHUB : https://github.com/lilDyNo94/Projet-machine-de-Turing.git

Lien :

https://machine-de-turing.fr/algorithmes.php

https://www.youtube.com/watch?v=P66h8D5Lkwk

https://github.com/sparkfun/LED_Matrix_Serial_Interface_RGB/tree/master

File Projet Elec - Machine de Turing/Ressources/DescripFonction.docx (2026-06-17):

# Tableaux de description des fonctions et des signaux

## Description d’une fonction

Fonction | FP1 | Traitements Numériques
Description / rôle | Réalise tous les traitements numériques nécessaires au bon fonctionnement du système
Signaux d'entrée | - MISO
Signaux de sortie | - MOSI, SLCK, SS, SCL
Signaux E/S | - SDA, ISCP

Fonction | FS 2.1 | Sélection mode
Description / rôle | Fonction qui sert à sélectionner le mode d’exécution pas à pas ou continu
Signaux d'entrée | - CmdSelMode
Signaux de sortie | - CmdMode
Signaux E/S | - NA

Fonction | FS 2.2 | Initialisation du programme
Description / rôle | Fonction qui permet d’initialiser les symboles et la tête de lecture
Signaux d'entrée | - CmdInit
Signaux de sortie | - Start, Stop
Signaux E/S | - NA

Fonction | FS 2.3 | Interfaçage d’entrée
Description / rôle | Fonction qui sert de réceptacle et de commande du MCU
Signaux d'entrée | - CmdMode, Start, Stop
Signaux de sortie | - SCL
Signaux E/S | - SDA

Description / rôle
Signaux d'entrée
Signaux de sortie
Signaux E/S

Fonction | FS 3.1 | Affichage Symbole
Description / rôle | Fonction réalisant l’affichage des symboles
Signaux d'entrée | - MOSI, SCLK, SS
Signaux de sortie | - MISO, DisplaySym
Signaux E/S | - NA

Fonction | FS 3.2 | Affichage de tête de lecture
Description / rôle | Fonction réalisant l’affichage de la tête de lecture
Signaux d'entrée | - MOSI, SCLK, SS
Signaux de sortie | - MISO, DisplayTete
Signaux E/S | - NA

Fonction | FA 1 | Alimentation
Description / rôle | Fonction qui alimente le système en électricité
Signaux d'entrée | - Energie
Signaux de sortie | - VCC
Signaux E/S | - NA

Fonction | FA 2 | Programmation In Situ
Description / rôle | Fonction permettant de charger le programme dans le mcu,
Signaux d'entrée | - NA
Signaux de sortie | - NA
Signaux E/S | - Données programme USB, Données programme ISCP

Fonction | FS 3.3 | Interfaçage sortie
Description / rôle | Fonction servant de réceptacle des signaux d’affichage des symboles et de la tête de la lecture
Signaux d'entrée | - DisplaySym, DisplayTete
Signaux de sortie | - InfoUser
Signaux E/S | - SDA

Fonction
Description / rôle
Signaux d'entrée
Signaux de sortie
Signaux E/S

Fonction
Description / rôle
Signaux d'entrée
Signaux de sortie
Signaux E/S

## Description des signaux

Signal | Fonctions concernées | Nature du signal (A/N/GP) | Taille entité | Grandeur et unité (U, I…) | Plage de variation - Niveaux | Excursion en fréquence | Valeur au repos | Contraintes temporelles | Conformité à une norme
| Description
MISO | FP1, FS3.1,FS3.2 | N | 1 | U(V) | Niveau haut/Niveau Bas | NA | NA | NA | SPI
| Signal généré par l’esclave pour communiquer avec le maitre
MOSI | FP1, FS3.1,FS3.2 | N | 1 | U(V) | Niveau haut/Niveau Bas | NA | NA | NA | SPI
| Signal généré par le maitre pour communiquer avec l’esclave
SCLK | FP1, FS3.1,FS3.2 | N | 1 | U(V) | Niveau haut/Niveau Bas | NA | NA | NA | SPI
| Signal de transmission de l’horloge par le maitre
SS | FP1, FS3.1, FS3.2 | N | 1 | U(V) | Niveau haut/Niveau Bas | NA | NA | NA | SPI
| Signal de sélection de l’esclave par le maitre
SDA | FP1, FS 2.3 | N | 1 | U(V) | Niveau haut/Niveau Bas | NA | 1 | NA | I2C
| Signal de transmission de données
SCL | FP1, FS 2.3 | N | 1 | U(V) | Niveau haut/Niveau Bas | NA | 1 | NA | I2C
| Signal de transmission de l’horloge
Commande User | FS 2.1, FS 2.2 | GP | NA | U(V) | NA | NA | NA | NA | NA
| Action d’appui des boutons par l’utilisateur
CmdMode | FS 2.1 | N | 1 | U(V) | Niveau haut/Niveau Bas | NA | NA | NA | NA
| Image du mode : niveau bas : pas à pas , niveau haut : continu
Start | FS 2.2 | N | 1 | U(V) | Niveau haut/Niveau Bas | NA | NA | NA | NA
| Image de l’appui sur le bouton de lancement
Stop | FS 2.2 | N | 1 | U(V) | Niveau haut/Niveau Bas | NA | NA | NA | NA
| Image de l’appui sur le bouton d’arrêt
Energie | FA 1 | A | 1 | U(V) | 230 v CC | NA | NA | NA | NA
| Courant alternatif monophasé !!! a verifier
VCC | FA 1 | A | 1 | U(V) | 5 v ou 3.3v cc | NA | NA | NA | NA
| Energie dont le MCU à besoin pour fonctionner
ISCP | FP 1, FA2 | N | 1 | NA | Niveau Haut/Niveau Bas | NA | 0 | NA | NA
| Signal de transmission des données pour la programmation in situ
Infos USer | FS3.1, FS3.2 | GP | NA | U(V) | NA | NA | NA | NA | NA
| Affichage de la tête de lecture et des symboles
DisplaySym | FS3.1 | GP | NA | U(V) | NA | NA | NA | NA | NA
| Affichage des symboles
DisplayTete | FS3.2 | GP | NA | U(V) | NA | NA | NA | NA | NA
| Affichage de la tête de lecture

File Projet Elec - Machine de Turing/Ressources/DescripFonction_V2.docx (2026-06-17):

# Tableaux de description des fonctions et des signaux

## 1. Description des fonctions

Ce paragraphe rassemble les tableaux fonctionnels définissant le rôle de chaque bloc ainsi que ses signaux d'entrée et de sortie associés.

Fonction | FP1 | Traitements Numériques
Description / rôle | Réalise tous les traitements numériques nécessaires au bon fonctionnement du système
Signaux d'entrée | IHM_In_Data, IHM_Out_Data
Signaux de sortie | IHM_In_Ack, IHM_Out_St
Signaux E/S | Prog_Data

Fonction | FS 2.1 | Sélection mode
Description / rôle | Fonction qui sert à sélectionner le mode d’exécution pas à pas ou continu
Signaux d'entrée | Input_Mode_Select
Signaux de sortie | Step_by_Step_Mode, Continuous_Mode
Signaux E/S | NA

Fonction | FS 2.2 | Initialisation du programme
Description / rôle | Fonction qui permet d’initialiser les symboles et la tête de lecture
Signaux d'entrée | Reset_System_Cmd
Signaux de sortie | Start, Up, Down, Select
Signaux E/S | NA

Fonction | FS 2.3 | Interfaçage d’entrée
Description / rôle | Fonction qui sert de réceptacle et de commande du MCU
Signaux d'entrée | Start, Up, Down, Select, Step_by_Step_Mode, Continuous_Mode
Signaux de sortie | SCL
Signaux E/S | SDA

Fonction | FS 3.1 | Affichage Symbole
Description / rôle | Fonction réalisant l’affichage des symboles
Signaux d'entrée | MOSI, SCLK, SS
Signaux de sortie | MISO, Symbol_Display
Signaux E/S | NA

Fonction | FS 3.2 | Affichage de tête de lecture
Description / rôle | Fonction réalisant l’affichage de la tête de lecture
Signaux d'entrée | MOSI, SCLK, SS
Signaux de sortie | MISO, Status_Display
Signaux E/S | NA

Fonction | FA 1 | Alimentation
Description / rôle | Fonction qui alimente le système en électricité
Signaux d'entrée | Energie
Signaux de sortie | VCC
Signaux E/S | NA

Fonction | FA 2 | Programmation In Situ
Description / rôle | Fonction permettant de charger le programme dans le mcu
Signaux d'entrée | NA
Signaux de sortie | NA
Signaux E/S | USB_Data, Prog_Data

## 2. Description des signaux

Ce tableau détaille l'ensemble des caractéristiques physiques, électriques et logiques de tous les signaux du système.

Signal | Fonctions concernées | Nature (A/N/GP) | Taille entité | Grandeur & Unité | Plage de variation | Excursion fréq. | Valeur repos | Contraintes temp. | Norme
MISO | FP1, FS3.1, FS3.2 | N | 1 | U (V) | Niveau Haut/Bas | NA | NA | NA | SPI

Description : Signal généré par l'esclave pour communiquer avec le maître.
MOSI | FP1, FS3.1, FS3.2 | N | 1 | U (V) | Niveau Haut/Bas | NA | NA | NA | SPI

Description : Signal généré par le maître pour communiquer avec l'esclave.
SCLK | FP1, FS3.1, FS3.2 | N | 1 | U (V) | Niveau Haut/Bas | NA | NA | NA | SPI

Description : Signal de transmission de l'horloge par le maître.
SS | FP1, FS3.1, FS3.2 | N | 1 | U (V) | Niveau Haut/Bas | NA | NA | NA | SPI

Description : Signal de sélection de l'esclave par le maître.
SDA | FP1, FS2.3 | N | 1 | U (V) | Niveau Haut/Bas | NA | 1 | NA | I2C

Description : Signal de transmission de données.
SCL | FP1, FS2.3 | N | 1 | U (V) | Niveau Haut/Bas | NA | 1 | NA | I2C

Description : Signal de transmission de l'horloge.
User_Cmd | FS2.1, FS2.2 | GP | NA | U (V) | NA | NA | NA | NA | NA

Description : Action d'appui des boutons par l'utilisateur.
Input_Mode_Select | FS2.1 | N | 1 | U (V) | Niveau Haut/Bas | NA | NA | NA | NA

Description : Image du mode : niveau bas = pas à pas, niveau haut = continu.
Reset_System_Cmd | FS2.2 | N | 1 | U (V) | Niveau Haut/Bas | NA | NA | NA | NA

Description : Image de l'appui sur le bouton d'initialisation.
Start | FS2.2 | N | 1 | U (V) | Niveau Haut/Bas | NA | NA | NA | NA

Description : Image de l'appui sur le bouton de lancement.
Energie | FA1 | A | 1 | U (V) | 230 V CA | 50 Hz | NA | NA | NA

Description : Courant alternatif monophasé (Réseau électrique).
VCC | FA1 | A | 1 | U (V) | 5 V ou 3.3 V CC | NA | NA | NA | NA

Description : Énergie continue dont le MCU a besoin pour fonctionner.
ISCP | FP1, FA2 | N | 1 | NA | Niveau Haut/Bas | NA | 0 | NA | NA

Description : Signal de transmission des données pour la programmation in situ.
Infos User | FS3.1, FS3.2 | GP | NA | U (V) | NA | NA | NA | NA | NA

Description : Affichage général combinant la tête de lecture et les symboles.
DisplaySym | FS3.1 | GP | NA | U (V) | NA | NA | NA | NA | NA

Description : Affichage des symboles.
DisplayTete | FS3.2 | GP | NA | U (V) | NA | NA | NA | NA | NA

Description : Affichage de la tête de lecture.
IHM_In_Data | FP1, FP2 | N | À définir | U (V) | Niveau Haut/Bas | NA | NA | NA | Spécifique

Description : Signal de données envoyé par l'interface d'entrée (FP2) vers l'unité de traitement numérique (FP1).
IHM_In_Ack | FP1, FP2 | N | 1 | U (V) | Niveau Haut/Bas | NA | NA | NA | Spécifique

Description : Signal d'acquittement renvoyé par le traitement numérique (FP1) à l'interface d'entrée (FP2).
IHM_Out_Data | FP1, FP3 | N | À définir | U (V) | Niveau Haut/Bas | NA | NA | NA | Spécifique

Description : Signal contenant les données d'affichage envoyé par le traitement numérique (FP1) vers l'interface de sortie (FP3).
IHM_Out_St | FP1, FP3 | N | À définir | U (V) | Niveau Haut/Bas | NA | NA | NA | Spécifique

Description : Signal d'état ou de contrôle renvoyé par l'interface d'affichage (FP3) vers le traitement numérique (FP1).
Prog_Data | FP1, FA2 | N | À définir | U (V) | Niveau Haut/Bas | NA | NA | NA | Spécifique

Description : Signal bidirectionnel d'échange de données de programmation entre le module In Situ (FA2) et le MCU (FP1).
USB_Data | FA2 | N | À définir | U (V) | Spécifique USB | Horloge USB | NA | NA | USB

Description : Liaison de données bidirectionnelle externe permettant de charger le programme via l'interface USB.
Step_by_Step_Mode | FS2.1, FS2.3 | N | 1 | U (V) | Niveau Haut/Bas | NA | NA | NA | NA

Description : Signal activant le mode d'exécution pas à pas envoyé à l'interfaçage d'entrée.
Continuous_Mode | FS2.1, FS2.3 | N | 1 | U (V) | Niveau Haut/Bas | NA | NA | NA | NA

Description : Signal activant le mode d'exécution continu envoyé à l'interfaçage d'entrée.
Up | FS2.2, FS2.3 | N | 1 | U (V) | Niveau Haut/Bas | NA | NA | NA | NA

Description : Signal d'incrémentation ou de déplacement vers le haut pour la configuration du système.
Down | FS2.2, FS2.3 | N | 1 | U (V) | Niveau Haut/Bas | NA | NA | NA | NA

Description : Signal de décrémentation ou de déplacement vers le bas pour la configuration du système.
Select | FS2.2, FS2.3 | N | 1 | U (V) | Niveau Haut/Bas | NA | NA | NA | NA

Description : Signal de sélection ou de validation d'une option envoyé à l'interfaçage d'entrée.
SYMBOL_DISPLAY | FS3.1 | GP | À définir | U (V) | Spécifique Matrice | NA | NA | NA | Matrice RGB

Description : Signal physique de commande envoyé à la matrice de LED (RGB_MATRIX) pour afficher les symboles.
STATUS_DISPLAY | FS3.2 | GP | À définir | U (V) | Spécifique Écran | NA | NA | NA | Écran LCD

Description : Signal physique de commande envoyé à l'écran LCD (LCD_SCREEN) pour afficher l'état de la tête de lecture.

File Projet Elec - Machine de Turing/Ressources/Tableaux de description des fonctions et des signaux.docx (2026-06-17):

# Tableaux de description des fonctions et des signaux

## Description d’une fonction

Fonction | FP1
Description / rôle | Traitement numérique : convertir la durée (4-20mA ou résistance) en commande moteur pendant la durée (V)
Signaux d'entrée | - Durée activité
Signaux de sortie | - Consigne vitesse
Signaux E/S

Fonction | Signal1
Description / rôle | Commande user
Signaux d'entrée
Signaux de sortie
Signaux E/S

Fonction
Description / rôle
Signaux d'entrée
Signaux de sortie
Signaux E/S

Fonction
Description / rôle
Signaux d'entrée
Signaux de sortie
Signaux E/S

Description / rôle
Signaux d'entrée
Signaux de sortie
Signaux E/S

Fonction
Description / rôle
Signaux d'entrée
Signaux de sortie
Signaux E/S

Fonction
Description / rôle
Signaux d'entrée
Signaux de sortie
Signaux E/S

Fonction
Description / rôle
Signaux d'entrée
Signaux de sortie
Signaux E/S

Fonction
Description / rôle
Signaux d'entrée
Signaux de sortie
Signaux E/S

Fonction
Description / rôle
Signaux d'entrée
Signaux de sortie
Signaux E/S

Fonction
Description / rôle
Signaux d'entrée
Signaux de sortie
Signaux E/S

Fonction
Description / rôle
Signaux d'entrée
Signaux de sortie
Signaux E/S

## Description des signaux

Signal | Fonctions concernées | Nature du signal (A/N/GP) | Taille entité | Grandeur et unité (U, I…) | Plage de variation - Niveaux | Excursion en fréquence | Valeur au repos | Contraintes temporelles | Conformité à une norme
| Description

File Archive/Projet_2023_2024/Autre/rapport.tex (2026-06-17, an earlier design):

\documentclass[12pt]{report}
\usepackage[utf8]{inputenc}
\usepackage[T1]{fontenc}
\usepackage[a4paper,left=2cm,right=2cm,top=2cm,bottom=2cm]{geometry}
\usepackage[french]{babel}
\usepackage[pdftex]{graphicx}
\usepackage{enumitem}
\usepackage{listings}
\usepackage{xcolor}
\usepackage{pdfpages}
\usepackage[a4paper,left=2cm,right=2cm,top=2cm,bottom=2cm]{geometry}
\usepackage{hyperref}
\usepackage{titlesec}
\usepackage{tocloft}
\hypersetup{
	colorlinks=true,
	linkcolor=blue,
	filecolor=magenta,      
	urlcolor=cyan,
	pdftitle={Machine de Turing},
	pdfpagemode=FullScreen,
}

\setlength{\parindent}{0cm}
\setlength{\parskip}{1ex plus 0.5ex minus 0.2ex}
\newcommand{\Sharp}{{\settoheight{\dimen0}{C}C\kern-.05em \resizebox{!}{\dimen0}{\raisebox{\depth}{\#}}}}
\newcommand{\hsp}{\hspace{20pt}}
\newcommand{\HRule}{\rule{\linewidth}{0.5mm}}

\definecolor{codegreen}{rgb}{0,0.6,0}
\definecolor{codegray}{rgb}{0.5,0.5,0.5}
\definecolor{codepurple}{rgb}{0.58,0,0.82}
\definecolor{backcolour}{rgb}{0.95,0.95,0.92}

\lstdefinestyle{mystyle}{
	backgroundcolor=\color{backcolour},   
	commentstyle=\color{codegreen},
	keywordstyle=\color{magenta},
	numberstyle=\tiny\color{codegray},
	stringstyle=\color{codepurple},
	basicstyle=\ttfamily\footnotesize,
	breakatwhitespace=false,         
	breaklines=true,                 
	captionpos=b,                    
	keepspaces=true,                 
	numbers=left,                    
	numbersep=5pt,                  
	showspaces=false,                
	showstringspaces=false,
	showtabs=false,                  
	tabsize=2
}

\lstset{style=mystyle}

\titleformat{\chapter}[block]
{\normalfont\huge\bfseries}{}{0pt}{}

\title{Machine de Turing}
\author{ALLEGRE--COMMINGES Clément et BROUARD Romain}
\date{~}
\begin{document}
	\maketitle
	\tableofcontents
	\chapter{Introduction}
	\section{Un peu d'histoire...}
	En 1928, Le mathématicien allemand David Hilbert énonce le "problème de la décision". Il se demande s'il est possible de trouver une méthode « effectivement calculable » pour décider si une proposition est démontrable. Pour résoudre ce problème, il faut caractériser ce qu'est un procédé effectivement calculable. C'est alors qu'Alan Turing, alors en thèse à Cambridge, conceptualise une machine universelle et prouve grâce à cette dernière que le problème de l'arrêt est indécidable, ce qui permet de donner une réponse négative au problème d'Hilbert pour l'arithmétique. C'est alors qu'Alan Turing introduit les concepts de programme et programmation.\\
	Ce concept de machine universelle, que nous appellerons désormais Machine de Turing Universelle (MTU) n'est pas réalisable puisqu'il s'agit d'un objet mathématique, dont on va détailler le fonctionnement plus tard. Néanmoins, une Machine de Turing à état fini peut-être construite, et la première vit donc le jour à Bletchley Park pendant la Seconde Guerre Mondiale, où Turing lui-même et une équipe de scientifique triés sur le volet par le MI6\footnote{Services de renseignement britanniques} construisirent une Machine de Turing pour casser les codes allemands générés par la machine Enigma. \cite{mtu_wikip}\\
	
	\section{Fonctionnement d'une MTU}
	Une MTU se compose de quatre éléments essentiels :
	\begin{itemize}[label=$-$]
		\item un ruban de taille infinie, divisé en cases.
		\item une tête de lecture/écriture (qu'on appellera simplement tête de lecture, même si elle permet également d'écrire sur le ruban)
		\item un état interne
		\item une table de transition.
	\end{itemize}
	Une machine de Turing traite des symboles. L'ensemble des symboles est appelé Alphabet.\\
	Le ruban permet d'accueillir des symboles qui seront lus et écrits par la tête de lecture.\\
	La tête de lecture permet de lire et écrire un symbole. Elle peut se déplacer vers la gauche ou la droite.\\
	\\
	Une machine de Turing fonctionne donc de la manière suivante :
	\begin{enumerate}
		\item La tête de lecture lit le symbole qu'elle pointe sur le ruban.
		\item En fonction de son état et du symbole lu, la tête de lecture écrit un symbole à la place de celui qu'elle a lu précédemment.
		\item Un déplacement est  choisi en fonction de l'état de la tête de lecture et du symbole lu.
		\item La tête de lecture change d'état.
		\item Le ruban se déplace vers la droite ou vers la gauche selon le déplacement choisi précédemment.
		\item Puis on recommence depuis le 1.
	\end{enumerate}
	 On peut donc résumer le fonctionnement comme cela : à chaque "cycle", on choisi un symbole à écrire, un nouvel état pour la tête de lecture, et un déplacement, en fonction d'un symbole lu et de l'état actuel. On peut donc définir une fonction de transition, qui va se charger de déterminer l'état futur d'une MTU en fonction de ton état courant. L'ensemble des fonctions de transition permettant de traiter un "mot" peut être représenté sous la forme d'une table de transitions ou d'un graphe de transitions.\\
	 Un mot traité est dit accepté si une Machine de Turing s'arrête en état final après l'avoir intégralement traité.\\
	 Une MTU possède forcément un nombre fini d'états, et elle a au moins deux états obligatoires : $q_O$ l'état initial, et $F$ un ensemble d'états d'acceptation.\\
	 \\
	 Une machine de Turing est donc définie par :\\
	 \begin{itemize}[label=$-$]
	 	\item $Q$ un ensemble fini d'états.\\
	 	\item $q_0$ un état initial tel que $q_0 \in Q$.\\
	 	\item $F$ un ensemble d'états d'acceptation tel que $F \subseteq Q$.\\
	 	\item $\Gamma$ un ensemble fini de symboles.\\
	 	\item $\Sigma$ un ensemble fini de symboles d'entrée tel que $\Sigma \subseteq \Gamma$.\\
	 	\item $B$ un symbole de ruban vide tel que $B \in \Gamma \setminus \Sigma$.
	 	\item $\delta$ une fonction de transition.\\
	\end{itemize}
	 Une fonction de transition se formalise donc comme ceci :\\
	 \[ \delta (q, Z) \to (p, Y, D) \]
	 avec $q$ l'état de la tête de lecture, $Z$ le symbole pointé, $p$ le nouvel état, $Y$ le nouveau symbole et $D$ le déplacement. \cite{mt_wikip}\\
	 \\
	 Exemple d'une table de transition pour une Machine de Turing acceptant le langage $L = \lbrace a^kb^k \, \vert \, k > 0 \rbrace$ avec $q_0$ comme état initial (représenté par une $\to$), et $q_4$ comme état d'acceptation (représenté par $\ast$):\\
	 \\
	 
	 \\
	 \\
	 Le but de ce projet va donc être de concevoir une Machine de Turing électronique fonctionnant tel que défini ci-dessus.
	 \chapter{Reprise de l'existant}
	 Le projet Machine de Turing se base sur un système existant dans le commerce. Le but est de concevoir une machine avec des fonctionnalités se rapprochant de ce modèle existant.\cite{site_mtu_fr} \\
	 Ce projet avait déjà été donné l'an passé, et nous avons eu accès à l'analyse et la maquette produite par le groupe qui s'en était chargé.\\
	 Leur maquette fonctionne, elle se compose de 8 boutons poussoirs, d'un micro-contrôleur PIC24FJ64GA002, et de deux matrices de LEDs SparkFun communiquant en SPI.\\
	 Nous avons trouvé que leur travail pouvait être amélioré, et nous avons proposé un cahier des charges ambitieux au client. Le travail d'analyse effectué l'an passé correspondait à peu près à la partie 1 de notre cahier des charges, c'est pourquoi nous avons décidé de rajouter deux autres parties, pour nous rapprocher le plus possible du système modèle.
	 \chapter{Conception}
	 \section{Cahier des charges}
	 Le cahier des charges est composé de trois parties. La partie 1 doit être traitée absolument, les parties 2 et 3 seront traitées si le temps nous le permet.
	 \subsection{Partie 1}
	 Dans un premier temps, le système conçu doit être capable de :
	 \begin{itemize}[label=$-$]
	 	\item exécuter un programme prédéfini (codé en dur dans le programme microcontrôleur).
	 	\item avoir un mode pas à pas pour l'exécution du programme.
	 	\item avoir un mode continu pour l'exécution du programme.
	 	\item gérer l'affichage de l'état du ruban.
	 	\item gérer l'affichage de la position de la tête de lecture.
	 	\item gérer l'affichage de la table de transition.
	 \end{itemize}
	 \subsection{Partie 2}
	 Dans un second temps, il faut rajouter :
	 \begin{itemize}[label=$-$]
	 	\item  la possibilité de sélectionner un programme via un menu.
	 	\item le stockage des programmes à sélectionner.
	 	\item l'initialisation manuelle du ruban et de la position de la tête de lecture.
	 \end{itemize}
	 \subsection{Partie 3}
	 Enfin pour obtenir un système complet, il faut implémenter :
	 \begin{itemize}[label=$-$]
	 	\item la programmation directement sur la machine d'une table de transition.
	 	\item l'enregistrement de la table de transition programmée dans le support de stockage.
	 	\item un reset de la programmation de la ligne en cours.
	 	\item l'affichage d'une description du programme.
	 \end{itemize}
 	\section{Définition des besoins}
 	 \subsection{Diagramme bête à corne}
 	 
 	 \subsection{Matrice Moscow}
 	 
	 \section{Conception Matérielle}
	 Pour concevoir notre système, nous avons décidé de traiter les trois parties en même temps, ce qui nous évite de devoir repasser par une phase de conception et d'adaptation lors de la réalisation des parties 2 et 3.\\
	 \subsection{SFN1}
	 Nous avons donc commencé par dessiner un Schéma fonctionnel de premier niveau, pour définir les différentes entrées et sorties de notre système :\\
	 
	\subsection{SFnD}
	On peut désormais rentrer un peu plus dans le détail avec un SF1D :\\
	
	On voit qu'on a quatre fonctions principales : une qui s'occupe de la gestion des entrées (FP2), une qui gère les sorties (FP3), une fonction de stockage pour stocker les tables de transitions (FP4), et du traitement numérique qui va piloter tout ça (FP1).\\
	On a aussi deux fonctions annexes : la fonction alimentation qui va se charger de fournir le courant nécessaire pour que la machine puisse fonctionner, et la fonction de programmation in-situ qui va faciliter le chargement du code dans la machine et nous éviter d'avoir à sortir le micro-contrôleur (MCU) à chaque fois.\\
	\\
	On voit que les fonctions FP2 et FP3 sont encore floues, on va donc les affiner en faisant des SF2D pour qu'on se rende compte de leur fonctionnement :\\
	\subsubsection{FP2 :}
	
	On voit clairement que FP2 est bien plus complexe qu'elle ne le parait, et forme un ensemble de fonctions plus spécifiques qui vont permettre à l'utilisateur d'interagir physiquement avec la machine, dans le but de la configurer, programmer, etc.
	\subsubsection{FP3 :}
	
	De la même manière que pour FP2, FP3 est en réalité un ensemble de fonctions plus spécifiques qui vont chacune avoir un rôle bien précis dans le retour des informations utilisateur. On a donc une grande variété de fonctions d'affichage qui vont, de la même manière que pour les sous-fonctions de FP2, être spécifiées ci-dessous.
	\subsection{Choix des technologies}
	\subsubsection{Communication}
	\paragraph{Bus I²C}
	Le nombre élevé d'entrées-sorties, du aux grand nombre de boutons poussoirs et composants d'affichage, nous a orienté sur l'utilisation d'expandeurs. Nous nous sommes orientés vers des expandeurs I²C, car l'utilisation du bus I²C nous permettait de gérer toutes nos entrées / sorties en utilisant uniquement deux broches sur le MCU (SDL et SCL). Nous avons ainsi essayé d'avoir un maximum de composants en I²C.\\
	\paragraph{Bus SPI}
	Nous nous sommes posés la question de l'utilisation du bus SPI pour notre ruban de LEDs. Nous avions aussi besoin de choisir notre type de communication avec la carte SD, et il se trouve que le bus SPI est très utilisé pour ce type de communication.\\
	\subsection{Spécifications des fonctions et de leurs signaux de communication}
	Nous avons donc spécifié ci-dessous, pour chaque fonction, son rôle ainsi que ses signaux d'entrée et/ou de sortie. Nous avons également précisé le rôle ainsi que ce qui fait l'essence même de chaque signal (type, etc.).\\
	
	
	
	
	
	
	
	
	
	
	
	\subsection{Choix des composants}
	\subsubsection{Composants}
	Nous avions donc besoin des composants suivants :
	\begin{itemize}[label=$-$]
		\item 2 rubans de LEDs RGB communicant en SPI
		\item 2 afficheurs 7 segments
		\item 1 écran LCD communicant en I²C
		\item 2 LEDs RBG
		\item 2 LEDs pour indiquer le mouvement, et 1 LED d'erreur
		\item 15 boutons poussoirs
		\item 2 commutateurs à bascule
		\item 1 lecteur de carte micro-SD communicant en SPI
		\item 3 expandeurs E/S - I²C de 16 I/O
	\end{itemize}
	\subsubsection{Choix du micro contrôleur}
	Nous avions déjà un PIC24FJ64GA002 car c'est le micro-contrôleur que le groupe précédent utilisait. Ce micro-contrôleur s'alimente en 3,3V et possède deux modules I²C et deux modules SPI. Comme nous utilisons des expandeurs pour toutes nous E/S, nous pouvons reprendre ce micro-contrôleur pour notre machine de Turing.\\
	\subsubsection{Commandes}
	Initialement, nous avions fait un premier choix de composants qui correspondait à nos spécificités. Tous les composants s'alimentent en 3,3 ou 5V. Toute la commande était prévue chez Farnell, mais nous avons dû nous raviser et mettre au point une autre liste à cause du délai de commande trop important.\\
	\paragraph{Commande initiale Farnell}
	\begin{itemize}[label=$-$]
		\item rubans de LEDs adressables \href{https://fr.aliexpress.com/item/1005006918408592.html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}{SK9822}
		\item afficheurs 7 segments \href{https://fr.farnell.com/broadcom-limited/hdsm-283b/afficheur-a-led-cms-7mm-bleu-cc/dp/1659312}{HDSM-283B}
		\item LEDs RGB \href{https://fr.farnell.com/kingbright/l-59eyc/led-5mm-tricolore/dp/1168662}{L-59EYC}
		\item expandeurs E/S - I²C \href{https://fr.farnell.com/microchip/mcp23017-e-sp/16-bit-expander-i-o-i2c-i-f/dp/1332088}{MCP23017}
		\item écran LCD I2C \href{https://fr.farnell.com/midas/mc21605c6w-bnmlwi-v2/afficheur-alphanumerique-16x2/dp/2748649}{MC21605C6W-BNMLWI-V2}
		\item boutons poussoirs \href{https://fr.farnell.com/panasonic/ese20c321/commutateur-bouton-pouss-momentane/dp/2079613}{ESE20C321}
		\item commutateurs \href{https://fr.farnell.com/multicomp/2as2t2a1m7re/switch-toggle-spdt-on-mom/dp/1550118}{2AS2T2A1M7RE}
	\end{itemize}
	\paragraph{Commande réelle (RS et Amazon)}
	\begin{itemize}[label=$-$]
		\item rubans de LEDs adressables \href{https://fr.aliexpress.com/item/1005006918408592.html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}{SK9822}
		\item expandeurs E/S - I²C \href{https://fr.farnell.com/microchip/mcp23017-e-sp/16-bit-expander-i-o-i2c-i-f/dp/1332088}{MCP23017}
		\item écran LCD I²C \href{https://fr.rs-online.com/web/p/afficheurs-monochromes-lcd/2644045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}{NHD-C0220BiZ-FSW-FBW-3V3M}\\
		\item LEDs RGB \href{https://fr.rs-online.com/web/p/leds/1651767?gb=s}{L-154A4SURKQBDZGW}
	\end{itemize}
	\subsection{Schéma représentatif}
	Le schéma ci-dessous nous donne une idée de ce à quoi pourrait ressembler notre machine de Turing une fois tous les composants montés :\\
	
	\\
	\\
	Nous avons essayé de respecter les connexions minimales recommandées de Microchip, trouvées dans la documentation de notre micro-contrôleur à la page 17 (voir \hyperref[sec:an4.1]{Annexe 4.1}).
	Légende :\\
	\begin{itemize}[label=$-$]
		\item 1: Interrupteur d'alimentation
		\item 2: Ruban de LEDs pour l'affichage des symboles
		\item 3: Ruban de LEDs pour l'affichage de la tête de lecture
		\item 4: Commutateur pour choisir entre le mode pas à pas et automatique
		\item 5: Bouton de réinitialisation lors de l'initialisation manuelle des rubans de LEDs
		\item 6: Ecran LCD pour l'affichage du menu
		\item 7, 8, 9: Boutons de navigation dans le menu (monter, sélectionner, descendre)
		\item 10: Bouton de lancement du programme. Sert également à passer à l'étape suivante en mode pas à pas
		\item 11 | 20: Afficheurs 7 segments pour l'affichage de l'état courant | de l'état suivant
		\item 12 | 21: LEDs RGB pour l'affichage du symbole courant | du symbole suivant
		\item 13, 14, 15, 16 | 22, 23, 24, 25: Boutons de décrémentation, validation, incrémentation, ré-initialisation de l'état et du symbole courant | de l'état et du symbole futur
		\item 17: Bouton de changement du déplacement pour l'état suivant
		\item 18, 19: LED représentant le déplacement pour l'état suivant (gauche si LED 18 allumée, droite si LED 19 allumée)
		\item 26: Bouton de sélection d'un état d'acceptation
		\item 27: Lecteur de carte micro-SD
	\end{itemize}
	\subsection{Schémas structurels}
	\subsubsection{MCU}
	
	\subsubsection{Expandeurs E/S - I²C}
	
	\subsubsection{Ecran LCD}
	
	\subsubsection{Affichage et programmation de l'état courant}
	
	\subsubsection{Affichage et programmation de l'état futur}
	
	\subsection{Tests}
	Nous avons manqué de temps pour effectuer des tests. Néanmoins nous en avons écrits un, permettant de tester la communication entre le micro-contrôleur, et l'expandeur I²C :\\
	
	\subsection{Conception Logicielle}
	Cette section ne traitera que la partie 1 du cahier des charges, les parties 2 et 3 ne pouvant être réalisées par manque de temps.\\
	La table de transition "Addition de deux binaires" que nous avons utilisé pour notre machine de Turing est disponible à \hyperref[sec:an4.2]{l'annexe 4.2}
	\subsection{Diagramme de Séquences}
	Les deux diagrammes de séquence ci-dessous montrent respectivement la phase d'initialisation et la phase de déroulement du programme au niveau du micro-contrôleur (on ne prend pas en compte les actions de l'utilisateur).\\
	Ce sont des diagrammes "best-case", c'est à dire qu'on ne prend pas en compte les erreurs qui pourraient survenir, et on déroule le fonctionnement du programme en supposant que tout se passe bien. Cela permet principalement de ne pas faire trop de diagrammes, ni de diagrammes trop longs.\\
	
	
	\subsection{Algorithme}
	Cet algorithme reprend les deux diagrammes de séquences ci-dessus.
	\begin{lstlisting}
		LIB_MACHINE_DE_TURING
		VARIABLES
			mcp23017_desc_t mpc23017_7_seg
			mcp23017_desc_t mcp23017_bp
			mcp23017_desc_t mcp23017_general
			i2c_desc_t I2CModule
		
		ENUMERATIONS
			mcp23017_err_t
			MCP23017_OK
			MCP23017_ERROR
		
		mcp23017_i2c_init_type_t
			INIT_WITH_I2C1
			INIT_WITH_I2C2
			INIT_ALREADY_DONE
		
		working_mode_t
			MANUAL_MODE
			AUTOMATIC_MODE
		
		STRUCTURES
		mcp23017_desc_t
			i2c_desc_t  *pi2c
			uint8_t     i2c_Address
		
		mcp23017_config_t
			i2c_desc_t  *pi2c;                      
			mcp23017_i2c_init_type_t    initType;   
			uint8_t i2c_Address;

		machine_de_turing_desc_t
			uint8_t state
			uint8_t symbol
			uint8_t next_state
			uint8_t next_symbol
			uint8_t next_move
		
		CONSTANTES
			MCP23017_7_SEG_ADDRESS      0100001
			MCP23017_BP_ADDRESS         0100010
			MCP23017_GENERAL_ADDRESS    0100011
		
			MCP23017_IOCONA_ADDRESS     0x0A
			MCP23017_IOA_ADDRESS        0x12
			MCP23017_IOB_ADDRESS        0x13
		
		DEBUT
			PROCEDURE Initialiser()
			VARIABLES
				mcp23017_err_t   Res;
				mcp23017_config_t    mcpCfg;
			DEBUT
				Configuration du port B en sortie
		
				// MPC23017 7 segs
				mcpCfg.pi2c = &I2CModule;
				Initialisation avec I2C_1
				Adresse = MCP23017_7_SEG_ADRESS;
		
				Res = mcp23017_init(@mpc23017_7_seg, @mcpCfg)
				SI Res != MCP23017_OK ALORS
					error_handler()
				FIN SI
			
				// MPC23017 BP
				mcpCfg.pi2c = &I2CModule;
				Initialisation avec I2C_1
				Adresse = MCP23017_BP_ADDRESS;
		
				Res = mcp23017_init(@mpc23017_bp, @mcpCfg)
				SI Res != MCP23017_OK ALORS
					error_handler()
				FIN SI
		
				// MPC23017 GENERAL
				mcpCfg.pi2c = &I2CModule;
				Initialisation avec I2C_1
				Adresse = MCP23017_GENERAL_ADDRESS;
		
				Res = mcp23017_init(@mpc23017_bp, @mcpCfg)
				SI Res != MCP23017_OK ALORS
					error_handler()
				FIN SI
		
			FIN Initialiser()
		
			PROCEDURE MainTask()
			VARIABLES
				uint8_t working_mode
				uint8_t next_step
				led_color_t rw_pointer_color
			DEBUT
				Res = mcp23017_read_reg(@mcp23017_bp, MCP23017_IOA_ADDRESS, @working_mode)
				SI Res != MCP23017_OK ALORS
					working_mode = MANUAL_MODE
				FIN SI
		
				TANT QUE mtu->state != ACCEPT_STATE FAIRE
					get_next_state(mtu->state, mtu->symbol, mtu->next_state)
					get_next_symbol(mtu->state, mtu->symbol, mtu->next_symbol)
					get_next_move(mtu->state, mtu->symbol, mtu->next_move)
					set_next_move(mtu->position, mtu->next_move)
		
					sk9822_set_LED_rgb(sk9822_1, mtu->position, mtu->symbol)
					sk9822_set_LED_rgb(sk9822_1, mtu->position, rw_pointer_color)
		
					RegValue = int_to_bin(mtu->state)
					Res = mcp23017_write_reg(@mcp23017_7_seg, MCP23017_IOA_ADDRESS, RegValue)
					SI Res != MCP23017_OK ALORS
						error_handler()
					FIN SI
		
					RegValue = int_to_bin(mtu->next_state)
					Res = mcp23017_write_reg(@mcp23017_7_seg, MCP23017_IOB_ADDRESS, RegValue)
					SI Res != MCP23017_OK ALORS
						error_handler()
					FIN SI
		
					RegValue = generate_general_reg(mtu->symbol, mtu->next_symbol, mtu->next_move)
					Res = mcp23017_write_reg(@mcp23017_general, MCP23017_IOA_ADDRESS, RegValue)
					SI Res != MCP23017_OK ALORS
						error_handler()
					FIN SI
		
					mtu->state = mtu->next_state
					mtu->symbol = mtu->next_symbol
		
					SI working_mode = MANUAL_MODE ALORS
						TANT QUE next_step = 0 FAIRE
						FIN TANT QUE
					SINON
						attendre(2000)
					FIN SI
				FIN TANT QUE
		FIN MainTask()
		
		PROCEDURE error_handler()
			allumer_led()
			TANT QUE 1 FAIRE
		FIN TANT QUE
		FIN error_handler
	\end{lstlisting}
	\subsection{Code}
	Le code ci-dessous implémente, avec quelques différences, l'algorithme précédent :
	\begin{lstlisting}[language=C]
	/**
	* @file    machine_de _turing_main.c
	* @author 	Romain BROUARD
	* @date	2024/05
	* @brief 	main programm of the machine de turing project
	*/
	
	#include "lib_machine_de_turing.h"
	
	#ifndef FCY
	#define FCY 400000UL
	#endif
	
	mcp23017_desc_t mcp23017_7_seg;
	mcp23017_desc_t mcp23017_bp;
	mcp23017_desc_t mcp23017_general;
	i2c_desc_t I2CModule;
	sk9822_desc_t sk9822_symbol;
	sk9822_desc_t sk9822_rw_head;
	machine_de_turing_desc_t *mtu;
	uint8_t next_step = 1;

	led_color_t red;
	led_color_t green;
	led_color_t lblue;
	
	void Initialiser() {
		mcp23017_err_t   Res;
		mcp23017_config_t    mcpCfg;
		
		TRISB = 0x0000;
		LATB = 0;
		
		mcpCfg.pi2c = &I2CModule;
		mcpCfg.initType = INIT_WITH_I2C1;
		
		// MCP23017 7 segs
		mcpCfg.i2c_Address = MCP23017_7_SEG;
		Res = mcp23017_init(&mcp23017_7_seg,&mcpCfg);
		if (Res != MCP23017_OK) error_handler();
		
		if(mcp23017_write_reg(&mcp23017_7_seg, REG_IOCONA, 0x00) == MCP23017_ERROR) {
			error_handler();
		}
		
		// MCP23017 BP
		mcpCfg.i2c_Address = MCP23017_BP;
		Res = mcp23017_init(&mcp23017_bp,&mcpCfg);
		if (Res != MCP23017_OK) error_handler();
		if(mcp23017_write_reg(&mcp23017_bp, REG_IOCONA, 0x00) == MCP23017_ERROR) {
			error_handler();
		}
		
		// MCP23017 GENERAL
		mcpCfg.i2c_Address = MCP23017_GENERAL;
		Res = mcp23017_init(&mcp23017_general,&mcpCfg);
		if (Res != MCP23017_OK) error_handler();
		if(mcp23017_write_reg(&mcp23017_general, REG_IOCONA, 0x00) == MCP23017_ERROR) {
			error_handler();
		}
		
		red.brightness = 0xFF;
		red.blue = 0;
		red.green = 0;
		red.red = 0xFF;
		
		green.brightness = 0xFF;
		green.blue = 0;
		green.green = 0xFF;
		green.red = 0;
		
		lblue.brightness = 0xFF;
		lblue.blue = 0xE6;
		lblue.green = 0xD8;
		lblue.red = 0xAD;
		
		for(uint8_t i = 0; i<3; i++) {
			sk9822_symbol.led_strip_buff[i] = lblue;
		}
		
		for(uint8_t i = 14; i<N_LED; i++) {
			sk9822_symbol.led_strip_buff[i] = lblue;
		}
		
		sk9822_symbol.led_strip_buff[4] = red;
		sk9822_symbol.led_strip_buff[6] = red;
		sk9822_symbol.led_strip_buff[8] = red;
		sk9822_symbol.led_strip_buff[12] = red;
		sk9822_symbol.led_strip_buff[13] = red;
		sk9822_symbol.led_strip_buff[5] = green;
		sk9822_symbol.led_strip_buff[7] = green;
		sk9822_symbol.led_strip_buff[10] = green;
		sk9822_symbol.led_strip_buff[11] = green;
		
		for(uint8_t i = 0; i<N_LED; i++) {
			sk9822_rw_head.led_strip_buff[i] = lblue;
		}
		sk9822_rw_head.led_strip_buff[13] = red;
		
		mtu->accept = 0;
		mtu->state = 1;
		mtu->next_symbol = RED;
		mtu->position = 12;
	}
	
	void MainTask() {
		uint8_t working_mode;
		uint8_t segValue;
		uint8_t genValue;
		if(mcp23017_read_reg(&mcp23017_bp, REG_GPIOA, &working_mode) == MCP23017_ERROR) {
			working_mode = MANUAL_MODE;
		}
		
		while(!mtu->accept) {
			get_next_transition(mtu);
			
			segValue = int_to_bin(mtu->state);
			if(mcp23017_write_reg(&mcp23017_7_seg, REG_OLATB, segValue) == MCP23017_ERROR) {
				error_handler();
			}
			segValue = int_to_bin(mtu->next_state);
			if(mcp23017_write_reg(&mcp23017_7_seg, REG_OLATA, segValue) == MCP23017_ERROR) {
				error_handler();
			}
			
			genValue = generate_general_reg_value(mtu->symbol, mtu->next_symbol, mtu->next_move);
			if(mcp23017_write_reg(&mcp23017_7_seg, REG_OLATB, segValue) == MCP23017_ERROR) {
				error_handler();
			}
			
			sk9822_rw_head.led_strip_buff[mtu->position] = lblue;
			sk9822_rw_head.led_strip_buff[mtu->next_move] = red;
			mtu->state = mtu->next_state;
			mtu->position = mtu->next_move;
			mtu->symbol = mtu->next_symbol;
			
			if(!working_mode) {
				while(next_step);
			}
			
		}
	}
	
	void error_handler(void){
		LATBbits.LATB15 = 1;
		__delay_ms(500);
	}
	\end{lstlisting}
	\chapter{Synthèse}
	Nous sommes conscient d'avoir vu grand, trop grand. Aujourd'hui, nous pensons avoir une partie d'analyse plutôt solide, nous avons également du code, et nous pensons qu'avec du temps en plus, nous aurions pu arriver à une maquette, au moins de la partie 1. Nous avons manqué de chance vis-à-vis des composants, notamment du ruban de LEDs puisque celui qu'on a reçu ne marche pas.\\
	Nous sommes fiers du travail réalisé, l'analyse est là, les composants sont là, le code est partiellement là, et nous avons pu véritablement mettre en pratique tout ce que nous avons appris en AMIIC et Programmation MCU lors de cette année.\\
	\\
	Ce rapport ne contient pas tous les documents produits, le reste des est disponible dans le dépôt Teams, ou bien sur github, au lien suivant : \url{https://github.com/romain327/machine-turing}. On y trouve notamment les datasheets des composants utilisés, le projet MPLABX contenant les différentes librairies, les schémas structurels, etc.\\
	\chapter{Remerciements}
	Nous remercions Mr. Bocquillon pour nous avoir encadré tout au long de ce projet.\\
	Nous remercions Mr. Rolland pour ses avis et conseils nous ayant permis d'affiner notre analyse.\\
	Nous remercions nos camarades de classe : Lucien, François et Kevin pour avoir répondu à nos questions et nous avoir conseillé.\\
	\chapter{Annexes}
	Ce rapport a été écrit en LaTeX, et la bibliographie réalisée avec BibTeX.
	\section{Connexions minimales recommandées}
	\label{sec:an4.1}
	
	\section{Table de transition "Addition de deux nombres binaires"}
	\label{sec:an4.2}
	
	\bibliographystyle{plain}
	\bibliography{biblio}
	
\end{document}

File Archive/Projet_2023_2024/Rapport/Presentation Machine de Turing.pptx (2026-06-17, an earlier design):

## Machine de Turing

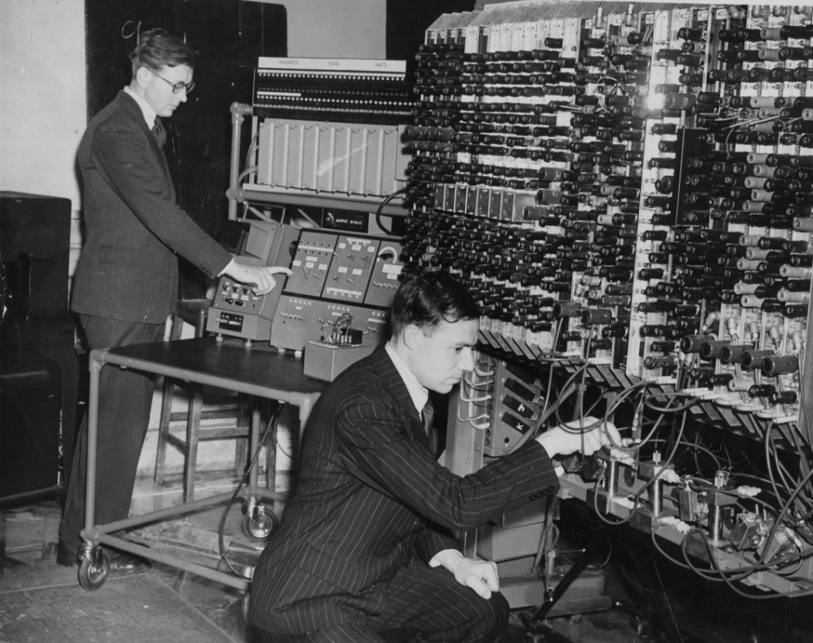
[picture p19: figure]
L'ordinateur et les échecs – Loti News

Par Romain BROUARD
et Clément ALLEGRE—COMMINGES
Encadrant: BOCQUILLON Ronan

## Sommaire:

## Présentation du Projet

Machine de Turing :

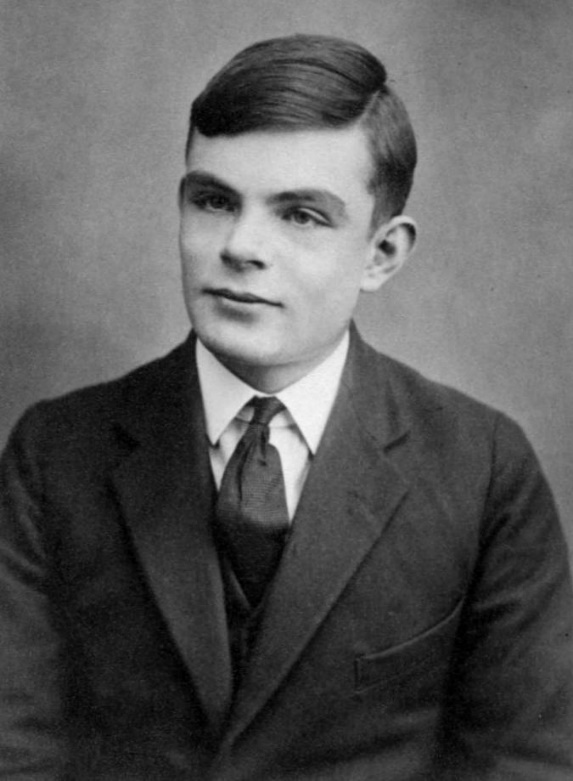
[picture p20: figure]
Alan Turing — Wikipédia
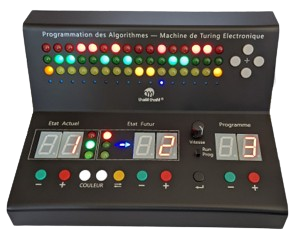
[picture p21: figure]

## Fonctionnement de la Machine

Exemple d’une table de transition pour l’acceptation du langage L = { a^k b^k | k > 0}

− Q un ensemble fini d'états.
− q0 un état initial tel que q0 ∈ Q.
− F un ensemble d'états d'acceptation tel que F ⊆ Q.
− Γ un ensemble fini de symboles.
− Σ un ensemble fini de symboles d'entrée tel que Σ ⊆ Γ.
− B un symbole de ruban vide tel que B ∈ Γ\Σ.
− δ une fonction de transition.

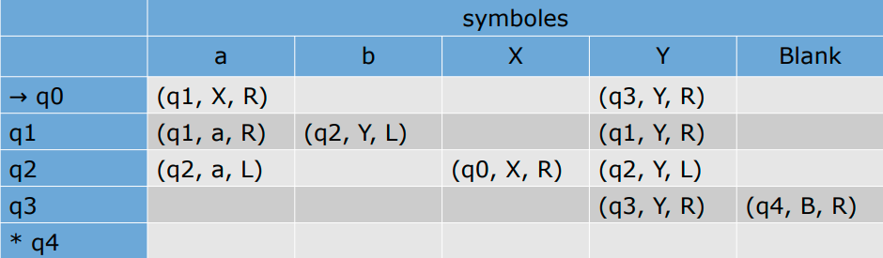
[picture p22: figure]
Table de transition

## Bête à Corne / SF1D

A qui rend-il service ?

- Étudiants en info
- Enseignants

Sur quoi agit-il?

- Exécution de programmes prédéfinis
- Affichage état ruban, et position de la tête de lecture

- Étudiants en info
- Enseignants

Machine de Turing à état fini capable de traiter des programmes prédéfinis

## Cahier des Charges

Partie 1
− exécuter un programme
− mode pas à pas/ continu
− affichage de l'état du ruban, position de la tête de lecture et table de transition
Partie 2
− sélection programme via menu.
− stockage des programmes.
− initialisation manuelle ruban de LED et position tête de lecture.
Partie 3
− programmation sur la machine d'une table de transition.
− enregistrement table de transition dans un stockage externe.
− reset programmation de la ligne en cours.
− affichage d'une description du programme.

## Matrice MOSCOW

Must Have

Should Have

- Machine de Turing capable au moins de faire l’addition de 2 nombres
- Mode continu/pas à pas pour l'exécution du programme
- Affichage de l'état du ruban
- Affichage de la position de la tête de lecture
- Gérer l'affichage de la table de transition

- La possibilité de sélectionner un programme via un menu
- Stockage des programmes à sélectionner
- Initialisation manuelle du ruban et de la position de la tête de lecture.

Could Have

Won’t Have

- Programmation directement sur la machine d'une table de transition
- Enregistrement de la table de transition programmée dans le support de stockage
- Reset de la programmation de la ligne en cours
- Affichage d'une description du programme

- Codage table de transition à l’aide d’un clavier

## Conception générale

SFN1 :

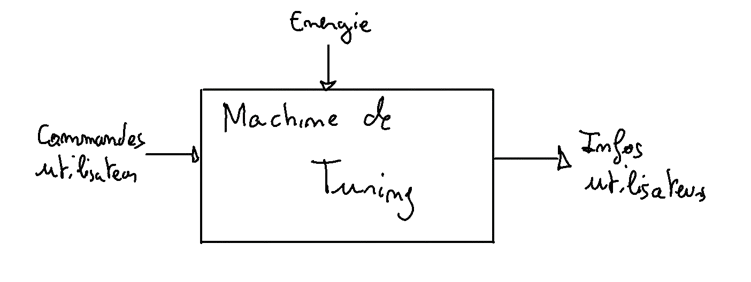
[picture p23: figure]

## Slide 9

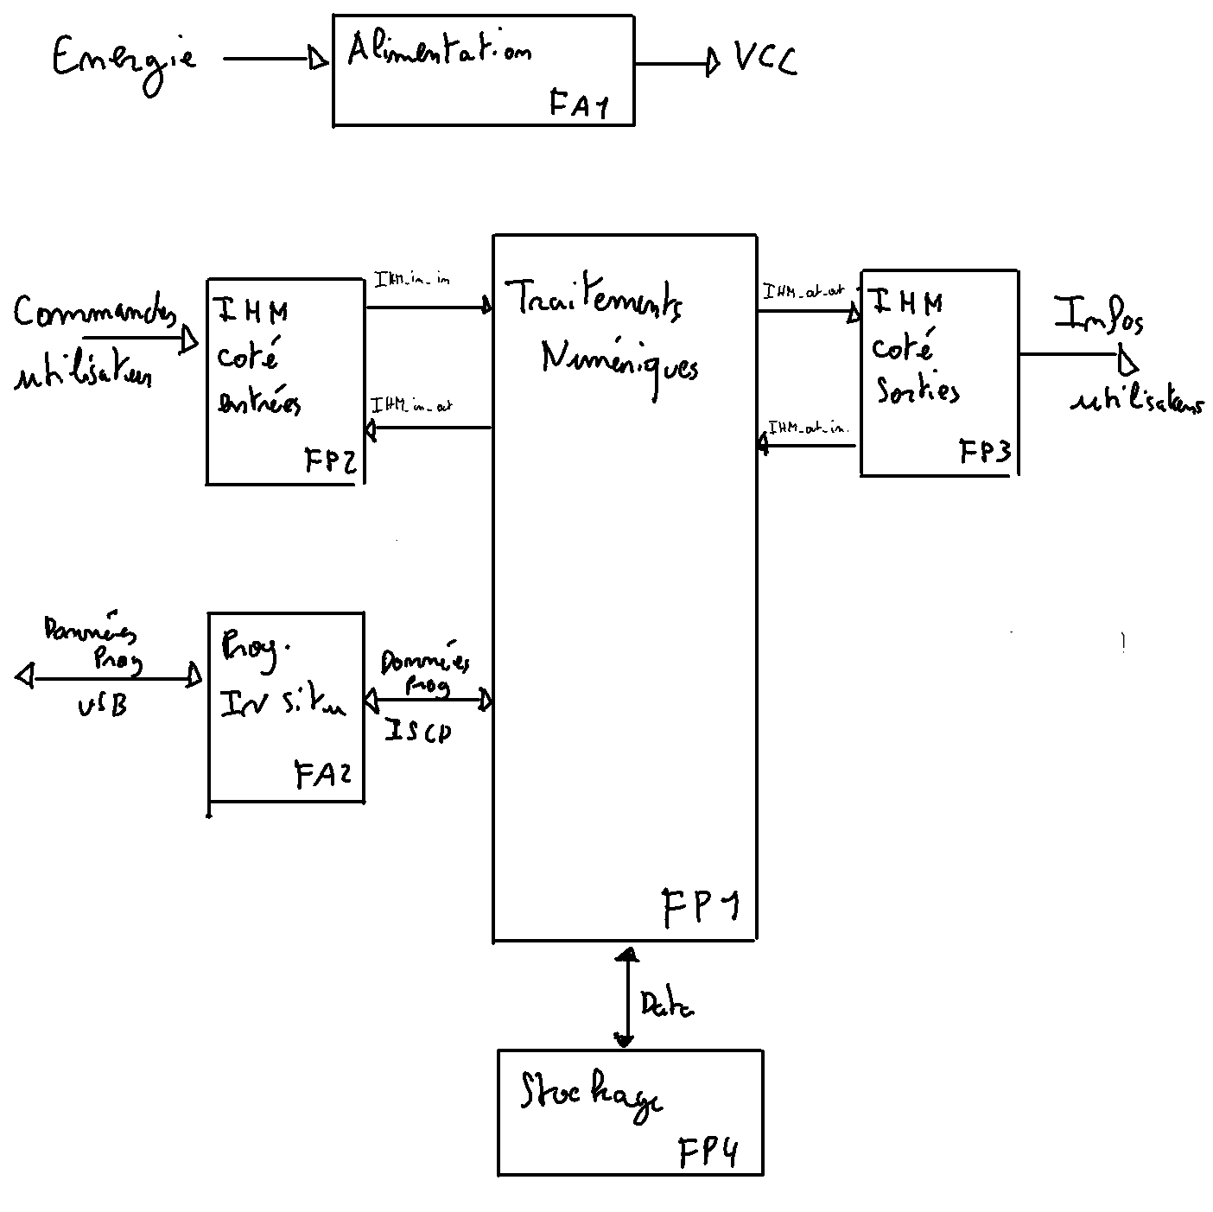
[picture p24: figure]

SF1D :

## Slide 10


SF2D FP2 :

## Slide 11


SF2D FP3 :

## Analyse des fonctions et signaux


## Choix des composants (1/2)

Commande initiale chez Farnell :
- Ecran LCD I2C : MC21605C6W-BNMLWI-V2
- Afficheurs 7 segments : HDSP-7513
- LEDs RGB : L-59EYC


## Choix des composants (2/2)

Commande réelle chez RS

- Alimentation: 5V et 3.3V
-> MB102


- Expander -> MCP23017


- 7 segments -> HD1143G


- Ecran LCD ->
HD1143G

- Ruban de LEDs ->
SK9822


- LED RGB

## PIC24FJ64GA002

- Nombre de broches : 28 broches (26, 2 cassées)
- Nb E/S analogiques : 10 bits (16 max)
- Nb d'interfaces série : 1 x UART, 2 x SPI, 2 x I2C
- Fréquence maximale d'horloge : 32 MHz


## Schéma électrique


## Schéma électrique


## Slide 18


## Schéma électrique


## Schéma électrique


## Conception Logicielle

- Diagrammes de Séquences
- Algorithmes

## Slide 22


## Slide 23


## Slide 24


## Implémentation

Librairie MCP23017
Librairie SK9822
Librairies I2C, SPI
Librairie « générale »
Librairie de calculs (table de transition, conversions, etc.)

## Bilan

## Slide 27

Avez-vous des questions?

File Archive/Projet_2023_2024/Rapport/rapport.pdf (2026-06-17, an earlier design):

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

# Table des matières

1 Introduction | 2
2 Reprise de l'existant | 5
3 Conception | 6
3.3.4 | Spécications des fonctions et de leurs signaux de communication . . . . 13
4 Synthèse | 32
5 Remerciements | 33
6 Annexes | 34

# Introduction

1.1 Un peu d'histoire...

En 1928, Le mathématicien allemand David Hilbert énonce le "problème de la décision". Il se demande s'il est possible de trouver une méthode eectivement calculable pour décider si une proposition est démontrable. Pour résoudre ce problème, il faut caractériser ce qu'est un procédé eectivement calculable. C'est alors qu'Alan Turing, alors en thèse à Cambridge, conceptualise une machine universelle et prouve grâce à cette dernière que le problème de l'arrêt est indécidable, ce qui permet de donner une réponse négative au problème d'Hilbert pour l'arithmétique. C'est alors qu'Alan Turing introduit les concepts de programme et programmation.
Ce concept de machine universelle, que nous appellerons désormais Machine de Turing Universelle (MTU) n'est pas réalisable puisqu'il s'agit d'un objet mathématique, dont on va détailler le fonctionnement plus tard. Néanmoins, une Machine de Turing à état ni peut-être construite, et la première vit donc le jour à Bletchley Park pendant la Seconde Guerre Mondiale, où Turing lui-même et une équipe de scientique triés sur le volet par le MI6 ¹
construisirent une Machine de Turing pour casser les codes allemands générés par la machine Enigma. [1]

## 1.2 Fonctionnement d'une MTU

Une MTU se compose de quatre éléments essentiels :
− un ruban de taille innie, divisé en cases.
− une tête de lecture/écriture (qu'on appellera simplement tête de lecture, même si elle permet également d'écrire sur le ruban)
− un état interne
− une table de transition.
Une machine de Turing traite des symboles. L'ensemble des symboles est appelé Alphabet. Le ruban permet d'accueillir des symboles qui seront lus et écrits par la tête de lecture.
La tête de lecture permet de lire et écrire un symbole. Elle peut se déplacer vers la gauche ou la droite.

Une machine de Turing fonctionne donc de la manière suivante :
1. La tête de lecture lit le symbole qu'elle pointe sur le ruban.
2. En fonction de son état et du symbole lu, la tête de lecture écrit un symbole à la place de celui qu'elle a lu précédemment.
1. Services de renseignement britanniques

3. Un déplacement est choisi en fonction de l'état de la tête de lecture et du symbole lu.
4. La tête de lecture change d'état.
5. Le ruban se déplace vers la droite ou vers la gauche selon le déplacement choisi précédemment.
6. Puis on recommence depuis le 1.
On peut donc résumer le fonctionnement comme cela : à chaque "cycle", on choisi un symbole à écrire, un nouvel état pour la tête de lecture, et un déplacement, en fonction d'un symbole lu et de l'état actuel. On peut donc dénir une fonction de transition, qui va se charger de déterminer l'état futur d'une MTU en fonction de ton état courant. L'ensemble des fonctions de transition permettant de traiter un "mot" peut être représenté sous la forme d'une table de transitions ou d'un graphe de transitions.
Un mot traité est dit accepté si une Machine de Turing s'arrête en état nal après l'avoir intégralement traité.
Une MTU possède forcément un nombre ni d'états, et elle a au moins deux états obligatoires : qO l'état initial, et F un ensemble d'états d'acceptation.

Une machine de Turing est donc dénie par :

− Q un ensemble ni d'états.

− q0 un état initial tel que q0 ∈ Q.

− F un ensemble d'états d'acceptation tel que F ⊆ Q.

− Γ un ensemble ni de symboles.

− Σ un ensemble ni de symboles d'entrée tel que Σ ⊆ Γ.

− B un symbole de ruban vide tel que B ∈ Γ \ Σ.
− δ une fonction de transition.

Une fonction de transition se formalise donc comme ceci :

δ(q, Z) → (p, Y, D)

avec q l'état de la tête de lecture, Z le symbole pointé, p le nouvel état, Y le nouveau symbole et D le déplacement. [2]

Exemple d'une table de transition pour une Machine de Turing acceptant le langage L = {a

k
b

k
| k > 0} avec q0 comme état initial (représenté par une →), et q4 comme état d'acceptation (représenté par ∗) :


Le but de ce projet va donc être de concevoir une Machine de Turing électronique fonctionnant tel que déni ci-dessus.

# Reprise de l'existant

Le projet Machine de Turing se base sur un système existant dans le commerce. Le but est de concevoir une machine avec des fonctionnalités se rapprochant de ce modèle existant.[3]
Ce projet avait déjà été donné l'an passé, et nous avons eu accès à l'analyse et la maquette produite par le groupe qui s'en était chargé.
Leur maquette fonctionne, elle se compose de 8 boutons poussoirs, d'un micro-contrôleur PIC24FJ64GA002, et de deux matrices de LEDs SparkFun communiquant en SPI.
Nous avons trouvé que leur travail pouvait être amélioré, et nous avons proposé un cahier des charges ambitieux au client. Le travail d'analyse eectué l'an passé correspondait à peu près à la partie 1 de notre cahier des charges, c'est pourquoi nous avons décidé de rajouter deux autres parties, pour nous rapprocher le plus possible du système modèle.

# Conception

## 3.1 Cahier des charges

Le cahier des charges est composé de trois parties. La partie 1 doit être traitée absolument, les parties 2 et 3 seront traitées si le temps nous le permet.

### 3.1.1 Partie 1

Dans un premier temps, le système conçu doit être capable de :
− exécuter un programme prédéni (codé en dur dans le programme microcontrôleur). − avoir un mode pas à pas pour l'exécution du programme.
− avoir un mode continu pour l'exécution du programme.
− gérer l'achage de l'état du ruban.
− gérer l'achage de la position de la tête de lecture.
− gérer l'achage de la table de transition.

### 3.1.2 Partie 2

Dans un second temps, il faut rajouter :
− la possibilité de sélectionner un programme via un menu.
− le stockage des programmes à sélectionner.
− l'initialisation manuelle du ruban et de la position de la tête de lecture.

### 3.1.3 Partie 3

Enn pour obtenir un système complet, il faut implémenter :
− la programmation directement sur la machine d'une table de transition.
− l'enregistrement de la table de transition programmée dans le support de stockage. − un reset de la programmation de la ligne en cours.
− l'achage d'une description du programme.

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


## 3.3 Conception Matérielle

Pour concevoir notre système, nous avons décidé de traiter les trois parties en même temps, ce qui nous évite de devoir repasser par une phase de conception et d'adaptation lors de la réalisation des parties 2 et 3.

### 3.3.1 SFN1

Nous avons donc commencé par dessiner un Schéma fonctionnel de premier niveau, pour dénir les diérentes entrées et sorties de notre système :


### 3.3.2 SFnD

On peut désormais rentrer un peu plus dans le détail avec un SF1D :


On voit qu'on a quatre fonctions principales : une qui s'occupe de la gestion des entrées (FP2), une qui gère les sorties (FP3), une fonction de stockage pour stocker les tables de transitions (FP4), et du traitement numérique qui va piloter tout ça (FP1).
On a aussi deux fonctions annexes : la fonction alimentation qui va se charger de fournir le courant nécessaire pour que la machine puisse fonctionner, et la fonction de programmation in-situ qui va faciliter le chargement du code dans la machine et nous éviter d'avoir à sortir le micro-contrôleur (MCU) à chaque fois.

On voit que les fonctions FP2 et FP3 sont encore oues, on va donc les aner en faisant des SF2D pour qu'on se rende compte de leur fonctionnement :


FP2 :

On voit clairement que FP2 est bien plus complexe qu'elle ne le parait, et forme un ensemble de fonctions plus spéciques qui vont permettre à l'utilisateur d'interagir physiquement avec la machine, dans le but de la congurer, programmer, etc.


FP3 :

De la même manière que pour FP2, FP3 est en réalité un ensemble de fonctions plus spéciques qui vont chacune avoir un rôle bien précis dans le retour des informations utilisateur. On a donc une grande variété de fonctions d'achage qui vont, de la même manière que pour les sousfonctions de FP2, être spéciées ci-dessous.

### 3.3.3 Choix des technologies

Communication

Bus I²C Le nombre élevé d'entrées-sorties, du aux grand nombre de boutons poussoirs et composants d'achage, nous a orienté sur l'utilisation d'expandeurs. Nous nous sommes orientés vers des expandeurs I²C, car l'utilisation du bus I²C nous permettait de gérer toutes nos entrées / sorties en utilisant uniquement deux broches sur le MCU (SDL et SCL). Nous avons ainsi essayé d'avoir un maximum de composants en I²C.

Bus SPI Nous nous sommes posés la question de l'utilisation du bus SPI pour notre ruban de LEDs. Nous avions aussi besoin de choisir notre type de communication avec la carte SD, et il se trouve que le bus SPI est très utilisé pour ce type de communication.

### 3.3.4 Spécications des fonctions et de leurs signaux de communica- tion

Nous avons donc spécié ci-dessous, pour chaque fonction, son rôle ainsi que ses signaux d'entrée et/ou de sortie. Nous avons également précisé le rôle ainsi que ce qui fait l'essence même de chaque signal (type, etc.).


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



### 3.3.5 Choix des composants

Composants

Nous avions donc besoin des composants suivants : − 2 rubans de LEDs RGB communicant en SPI − 2 acheurs 7 segments
− 1 écran LCD communicant en I²C
− 2 LEDs RBG
− 2 LEDs pour indiquer le mouvement, et 1 LED d'erreur − 15 boutons poussoirs
− 2 commutateurs à bascule
− 1 lecteur de carte micro-SD communicant en SPI − 3 expandeurs E/S - I²C de 16 I/O

Choix du micro contrôleur

Nous avions déjà un PIC24FJ64GA002 car c'est le micro-contrôleur que le groupe précédent utilisait. Ce micro-contrôleur s'alimente en 3,3V et possède deux modules I²C et deux modules SPI. Comme nous utilisons des expandeurs pour toutes nous E/S, nous pouvons reprendre ce micro-contrôleur pour notre machine de Turing.

Commandes

Initialement, nous avions fait un premier choix de composants qui correspondait à nos spéci-cités. Tous les composants s'alimentent en 3,3 ou 5V. Toute la commande était prévue chez Farnell, mais nous avons dû nous raviser et mettre au point une autre liste à cause du délai de commande trop important.

Commande initiale Farnell
− rubans de LEDs adressables SK9822 (https://fr.aliexpress.com/item/1005006918408592.html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) − acheurs 7 segments HDSM-283B (https://fr.farnell.com/broadcom-limited/hdsm-283b/afficheur-a-led-cms-7mm-bleu-cc/dp/1659312) − LEDs RGB L-59EYC (https://fr.farnell.com/kingbright/l-59eyc/led-5mm-tricolore/dp/1168662)
− expandeurs E/S - I²C MCP23017 (https://fr.farnell.com/microchip/mcp23017-e-sp/16-bit-expander-i-o-i2c-i-f/dp/1332088)
− écran LCD I2C MC21605C6W-BNMLWI-V2 (https://fr.farnell.com/midas/mc21605c6w-bnmlwi-v2/afficheur-alphanumerique-16x2/dp/2748649) − boutons poussoirs ESE20C321 (https://fr.farnell.com/panasonic/ese20c321/commutateur-bouton-pouss-momentane/dp/2079613)
− commutateurs 2AS2T2A1M7RE (https://fr.farnell.com/multicomp/2as2t2a1m7re/switch-toggle-spdt-on-mom/dp/1550118)

Commande réelle (RS et Amazon) − rubans de LEDs adressables SK9822 (https://fr.aliexpress.com/item/1005006918408592.html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)
− expandeurs E/S - I²C MCP23017 (https://fr.farnell.com/microchip/mcp23017-e-sp/16-bit-expander-i-o-i2c-i-f/dp/1332088)
− écran LCD I²C NHD-C0220BiZ-FSW-FBW-3V3M (https://fr.rs-online.com/web/p/afficheurs-monochromes-lcd/2644045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)

− LEDs RGB L-154A4SURKQBDZGW (https://fr.rs-online.com/web/p/leds/1651767?gb=s)

### 3.3.6 Schéma représentatif

Le schéma ci-dessous nous donne une idée de ce à quoi pourrait ressembler notre machine de Turing une fois tous les composants montés :


Nous avons essayé de respecter les connexions minimales recommandées de Microchip, trouvées dans la documentation de notre micro-contrôleur à la page 17 (voir Annexe 4.1). Légende :

− 1 : Interrupteur d'alimentation
− 2 : Ruban de LEDs pour l'achage des symboles
− 3 : Ruban de LEDs pour l'achage de la tête de lecture
− 4 : Commutateur pour choisir entre le mode pas à pas et automatique
− 5 : Bouton de réinitialisation lors de l'initialisation manuelle des rubans de LEDs
− 6 : Ecran LCD pour l'achage du menu
− 7, 8, 9 : Boutons de navigation dans le menu (monter, sélectionner, descendre)
− 10 : Bouton de lancement du programme. Sert également à passer à l'étape suivante en mode pas à pas
− 11 | 20 : Acheurs 7 segments pour l'achage de l'état courant | de l'état suivant
− 12 | 21 : LEDs RGB pour l'achage du symbole courant | du symbole suivant
− 13, 14, 15, 16 | 22, 23, 24, 25 : Boutons de décrémentation, validation, incrémentation,
ré-initialisation de l'état et du symbole courant | de l'état et du symbole futur
− 17 : Bouton de changement du déplacement pour l'état suivant
− 18, 19 : LED représentant le déplacement pour l'état suivant (gauche si LED 18 allumée, droite si LED 19 allumée)
− 26 : Bouton de sélection d'un état d'acceptation
− 27 : Lecteur de carte micro-SD

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


### 3.3.8 Tests

Nous avons manqué de temps pour eectuer des tests. Néanmoins nous en avons écrits un, permettant de tester la communication entre le micro-contrôleur, et l'expandeur I²C :


### 3.3.9 Conception Logicielle

Cette section ne traitera que la partie 1 du cahier des charges, les parties 2 et 3 ne pouvant être réalisées par manque de temps.
La table de transition "Addition de deux binaires" que nous avons utilisé pour notre machine de Turing est disponible à l'annexe 4.2

### 3.3.10 Diagramme de Séquences

Les deux diagrammes de séquence ci-dessous montrent respectivement la phase d'initialisation et la phase de déroulement du programme au niveau du micro-contrôleur (on ne prend pas en compte les actions de l'utilisateur).
Ce sont des diagrammes "best-case", c'est à dire qu'on ne prend pas en compte les erreurs qui pourraient survenir, et on déroule le fonctionnement du programme en supposant que tout se passe bien. Cela permet principalement de ne pas faire trop de diagrammes, ni de diagrammes trop longs.

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



### 3.3.11 Algorithme

Cet algorithme reprend les deux diagrammes de séquences ci-dessus.

1 | LIB_MACHINE_DE_TURING
2 | VARIABLES
3 | mcp23017_desc_t mpc23017_7_seg
4 | mcp23017_desc_t mcp23017_bp
5 | mcp23017_desc_t mcp23017_general
6 | i2c_desc_t I2CModule

7
8 | ENUMERATIONS
9 | mcp23017_err_t
10 | MCP23017_OK
11 | MCP23017_ERROR

12
13 | mcp23017_i2c_init_type_t
14 | INIT_WITH_I2C1
15 | INIT_WITH_I2C2
16 | INIT_ALREADY_DONE

18 | working_mode_t
19 | MANUAL_MODE
20 | AUTOMATIC_MODE

21
22 | STRUCTURES
23 | mcp23017_desc_t
24 | i2c_desc_t | * pi2c
25 | uint8_t | i2c_Address

26
27 | mcp23017_config_t
28 | i2c_desc_t | * pi2c ;
29 | mcp23017_i2c_init_type_t | initType ;
30 | uint8_t i2c_Address ;

31

32
33 | machine_de_turing_desc_t
34 | uint8_t state
35 | uint8_t symbol
36 | uint8_t next_state
37 | uint8_t next_symbol
38 | uint8_t next_move

39
40 | CONSTANTES
41 | MCP23017_7_SEG_ADDRESS | 0100001
42 | MCP23017_BP_ADDRESS | 0100010
43 | MCP23017_GENERAL_ADDRESS | 0100011

44
45 | MCP23017_IOCONA_ADDRESS | 0 x0A
46 | MCP23017_IOA_ADDRESS | 0 x12
47 | MCP23017_IOB_ADDRESS | 0 x13

48
49 | DEBUT
50 | PROCEDURE Initialiser ()
51 | VARIABLES
52 | mcp23017_err_t | Res ;
53 | mcp23017_config_t | mcpCfg ;
54 | DEBUT
55 | Configuration du port B en sortie

56
57 | // MPC23017 7 segs
58 | mcpCfg . pi2c = & I2CModule ;
59 | Initialisation avec I2C_1
60 | Adresse = MCP23017_7_SEG_ADRESS ;

61
62 | Res = mcp23017_init ( @mpc23017_7_seg , @mcpCfg )
63 | SI Res != MCP23017_OK ALORS
64 | error_handler ()
65 | FIN SI

66
67 | // MPC23017 BP
68 | mcpCfg . pi2c = & I2CModule ;
69 | Initialisation avec I2C_1
70 | Adresse = MCP23017_BP_ADDRESS ;

71
72 | Res = mcp23017_init ( @mpc23017_bp , @mcpCfg )
73 | SI Res != MCP23017_OK ALORS
74 | error_handler ()
75 | FIN SI

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

43 | if( mcp23017_write_reg (& mcp23017_7_seg , REG_IOCONA , 0 x00 ) ==
| MCP23017_ERROR ) {
44 | error_handler () ;
45 | }

46
47 | // MCP23017 BP
48 | mcpCfg . i2c_Address = MCP23017_BP ;
49 | Res = mcp23017_init (& mcp23017_bp ,& mcpCfg ) ;
50 | if ( Res != MCP23017_OK ) error_handler () ;
51 | if( mcp23017_write_reg (& mcp23017_bp , REG_IOCONA , 0 x00 ) == MCP23017_ERROR )
| {
52 | error_handler () ;
53 | }

54
55 | // MCP23017 GENERAL
56 | mcpCfg . i2c_Address = MCP23017_GENERAL ;
57 | Res = mcp23017_init (& mcp23017_general ,& mcpCfg ) ;
58 | if ( Res != MCP23017_OK ) error_handler () ;
59 | if( mcp23017_write_reg (& mcp23017_general , REG_IOCONA , 0 x00 ) ==
| MCP23017_ERROR ) {
60 | error_handler () ;
61 | }

62
63 | red . brightness = 0 xFF ;
64 | red . blue = 0;
65 | red . green = 0;
66 | red . red = 0 xFF ;

67
68 | green . brightness = 0 xFF ;
69 | green . blue = 0;
70 | green . green = 0 xFF ;
71 | green . red = 0;

72
73 | lblue . brightness = 0 xFF ;
74 | lblue . blue = 0 xE6 ;
75 | lblue . green = 0 xD8 ;
76 | lblue . red = 0 xAD ;

77
78 | for( uint8_t i = 0; i <3; i ++) {
79 | sk9822_symbol . led_strip_buff [ i ] = lblue ;
80 | }

81
82 | for( uint8_t i = 14; i < N_LED ; i ++) {
83 | sk9822_symbol . led_strip_buff [ i ] = lblue ;
84 | }

85
86 | sk9822_symbol . led_strip_buff [4] = red ;
87 | sk9822_symbol . led_strip_buff [6] = red ;
88 | sk9822_symbol . led_strip_buff [8] = red ;
89 | sk9822_symbol . led_strip_buff [12] = red ;
90 | sk9822_symbol . led_strip_buff [13] = red ;
91 | sk9822_symbol . led_strip_buff [5] = green ;
92 | sk9822_symbol . led_strip_buff [7] = green ;
93 | sk9822_symbol . led_strip_buff [10] = green ;
94 | sk9822_symbol . led_strip_buff [11] = green ;

95
96 | for( uint8_t i = 0; i < N_LED ; i ++) {
97 | sk9822_rw_head . led_strip_buff [ i ] = lblue ;
98 | }

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

# Synthèse

Nous sommes conscient d'avoir vu grand, trop grand. Aujourd'hui, nous pensons avoir une partie d'analyse plutôt solide, nous avons également du code, et nous pensons qu'avec du temps en plus, nous aurions pu arriver à une maquette, au moins de la partie 1. Nous avons manqué de chance vis-à-vis des composants, notamment du ruban de LEDs puisque celui qu'on a reçu ne marche pas.
Nous sommes ers du travail réalisé, l'analyse est là, les composants sont là, le code est partiellement là, et nous avons pu véritablement mettre en pratique tout ce que nous avons appris en AMIIC et Programmation MCU lors de cette année.

Ce rapport ne contient pas tous les documents produits, le reste des est disponible dans le dépôt Teams, ou bien sur github, au lien suivant : https://github.com/romain327/machine-turing. On y trouve notamment les datasheets des composants utilisés, le projet MPLABX contenant les diérentes librairies, les schémas structurels, etc.

# Remerciements

Nous remercions Mr. Bocquillon pour nous avoir encadré tout au long de ce projet.
Nous remercions Mr. Rolland pour ses avis et conseils nous ayant permis d'aner notre analyse. Nous remercions nos camarades de classe : Lucien, François et Kevin pour avoir répondu à nos questions et nous avoir conseillé.

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


# Bibliographie

[1] https://fr.wikipedia.org/wiki/Machine_de_Turing_universelle.
[2] https://fr.wikipedia.org/wiki/Machine_de_Turing.
[3] https://machine-de-turing.fr/.
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

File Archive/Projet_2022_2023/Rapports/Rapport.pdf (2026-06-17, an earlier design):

# Machine de Turing

## Rapport de projet électronique


Etudiants: | LAZOUZI Jihane
| ZORZETTO Damien
Encadrant : | BOCQUILLON Ronan

Année universitaire : 2022/2023


## Sommaire

## Introduction générale

a. Contexte du projet

Afin d’avoir un dispositif concret et un outil pédagogique qui simule le fonctionnement de la machine de Turing. Nous essayons à travers notre projet de présenter à l’aide d’une matrice LED, et pour une opération arithmétique donnée, de modéliser le fonctionnement de la machine, en commençant par la saisie des entrées (nombres binaires dans notre cas), et jusqu’aux sorties (l’affichage du résultat de l’opération choisie). La machine doit faire l’opération arithmétique demandée à travers une succession de changement d’états, sans faire l’opération elle-même.

b. Principe de fonctionnement

Etant dans un état initial, la machine décide selon le caractère c pointé par la tête de lecture et l’état actuelle dans lequel elle est :

- Le caractère par lequel le caractère c sera remplacé
- Le déplacement de la tête de lecture
- Le prochain état dans lequel la machine sera

La même procédure s’exécute jusqu’à arriver à un état final, qui lui décide la fin de changement d’états, pour indiquer que le résultat affiché en sortie est bien le résultat attendu.

Pendant l’exécution de changement d’état, la sortie peut changer mais elle ne représente pas le résultat attendu tant qu’elle n’est pas arrivée à un état final, elle est dans des états intermédiaires.

c. Cahier de charges

Une machine capable d’exécuter des opérations arithmétiques sur des nombres binaires (au moins addition dans un premier temps), en suivant le principe de fonctionnement de la machine d’états (machine de Turing) qui doit être visualisé à l’aide d’une matrice LED.

Conception de la machine :

- Des boutons pour :
1. Un déplacement à droite de la position de la tête de lecture tout au long du ruban (d’une colonne n à une colonne n+1)
2. Un déplacement à gauche de la position de la tête de lecture tout au long du ruban (d’une colonne n à une colonne n-1)
3. Un changement de symbole de la case pointée par la tête de lecture au suivant (selon un ordre précis de symboles prédéfinis)
4. Choix de l’opération arithmétique addition
5. Choix de l’opération arithmétique soustraction
6. Choix de l’opération arithmétique multiplication
7. Choix de l’opération arithmétique division
- Représentation du ruban infini par une matrice LED avec :
- Une largeur égale à la taille du ruban (supposé fini)
- Chaque ligne représentera un symbole
- Une ligne réservée pour la représentation de la position de la tête de lecture

Ainsi le nombre de symboles reconnu par la machine sera égale au nombre de lignes de la matrice LED moins un, et le nombre de symboles significatif en entrée, longueur de la donnée à traiter par la machine, indépendamment de leur signification, données réelles ou contraintes de saisie (séparateurs ..) sera égale au nombre de colonnes.

## Machine de Turing

a. Définition formelle

D’abord la machine de Turing comporte :

- Un ruban infini, divisé en cases consécutives et chaque case contient un symbole d’un alphabet donné
- Une tête de lecture/écriture, qui se déplace tout au long du ruban pour lire et écrire les symboles de l’alphabet dans les cases
- Un registre d’état, qui mémorise l’état courant de la machine.
- Une table d’actions, qui indique pour un caractère lu de la case pointée par la tête de lecture et l’état actuelle de la machine :
- Le caractère à écrire dans cette case
- Un déplacement vers la gauche ou la droite ou ne pas se déplacer
- Le nouvel état dans lequel la machine sera
b. Notions et précisions

Alphabet reconnu par la machine revient à dire que si un symbole d’une case de ruban n’appartient à l’alphabet, le symbole ne sera pas reconnu

Le premier état dans lequel la machine se trouve initialement est appelé état de départ. Il existe un seul état de départ pour chaque traitement (algorithme)

Les états intermédiaires sont les états dans laquelle la machine se trouve, avec un changement au niveau de sa sortie, avant que la machine finisse le traitement. Même si les symboles changent en ruban, ils ne reflètent pas le résultat attendu avant qu’un état final soit atteint.

Plusieurs états finaux différents en interprétation peuvent exister.

## Analyse du projet

a. Bête à cornes

Pour notre projet, nous avons commencé par une bête à cornes pour préciser à qui notre machine rendra service ? Sur quoi il va agir ? Dans quel but ?


b. Schéma fonctionnel de niveau 1

Pour le schéma fonctionnel de niveau 1, nous avons conçu le schéma suivant :


Cinq fonctions principales ; déplacement de la position de la tête de lecture, choix de l’opération arithmétique, lancement du programme, traitements numériques et affichage des symboles présents dans les cases de la tête de la bande

c. Matrice MOSCOW

Après établir le cahier de charges, le négocier et valider avec le client, nous sommes arrivés aux spécifications :

- Indispensables qui doivent exister dans notre machine (Must Have)
- Obligatoire mais pas indispensables (Should Have)
- Qui peuvent être intégrer dans des prochaines mises à jour (Could Have)
- Qui ne seront jamais intégrer dans notre produit (Won’t Have)


## Conception matérielle

a. Choix de composants

Selon le cahier de charges et des exigences clients, les choix de composants suivants étaient faits :

- Choix de la matrice

Pour le choix de la matrice, plusieurs critères ont été pris en compte pour garantir le fonctionnement attendu et satisfaire aux exigences de clients :

- Etant donné que la machine doit faire des opérations arithmétiques sur des nombres binaires, le nombre de symboles pour la machine sera donc 3 (le 0 binaire + le 1 binaire + le caractère nul) + la ligne réservée pour l’affichage de la position de la tête de lecture. Le nombre minimum de lignes de la matrice LED doit être égale à 4.
- Le nombre de colonnes de la matrice représentera la longueur des 2 nombres binaires saisis + 1 colonne pour les séparer (au milieu) + 2 colonnes pour les délimiter de la gauche et de la droite. Les nombres finalement saisis seront sous la forme :

D_G + X + S + Y + D_D (avec D_G : symbole pour limite gauche, D_D : symbole pour limite droite, S : symbole pour séparer les 2 nombres binaires, X : premier nombre binaire, Y deuxième nombre binaire)

Ainsi, nous avons choisi 2 matrices LED de taille 8x8 avec un nombre de lignes total égale à 8 et un de colonnes total égale à 16 pour avoir une longueur raisonnable de nombres binaires et pour des LEDs suffisamment grandes pour l’affichage des résultats. Le but étant pédagogique, la taille des LEDs doit être suffisamment grande et un affichage de plusieurs couleurs doit être possible, afin de bien visionner le fonctionnement.

- Choix du microprocesseur :

Pour le choix de notre microcontrôleur qui devra contrôler notre matrice un certain nombre de points à guider nos choix :

- Etant donné que le microcontrôleur est censé communiquer avec la matrice il est impératif que ce dernier puisque communiquer en SPI
- Notre machine de Turing comporte un certain nombre de boutons poussoir qui nous permet d'interagir avec la machine, le nombre de boutons poussoir s'élève à un nombre de 7.
- Le microcontrôleur devez avoir une fréquence d’horloge suffisante pour que l'utilisateur les opérations effectuées par le microcontrôleur soit le plus fluide possible
- Le microcontrôleur devait pouvoir accueillir notre programme et avoir un espace mémoire suffisant pour recevoir des modifications futures

À la suite de nos recherches nous avons trouvé un microcontrôleur qui nous permettait de répondre à ces contraintes le PIC24FJ64GA002 :
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

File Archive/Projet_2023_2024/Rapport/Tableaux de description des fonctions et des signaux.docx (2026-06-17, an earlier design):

# Tableaux de description des fonctions et des signaux

## Description d’une fonction

Fonction | FP1 | Traitements numériques
Description / rôle | Réalise tous les traitements numériques nécessaires au bon fonctionnement du système.
Signaux d'entrée | - MISO
Signaux de sortie | - MOSI, SCLK, SS, SCL
Signaux E/S | - SDA, ISCP

Fonction | FS2.1 | Sélection du mode
Description / rôle | Fonction qui sert à sélectionner le mode d’exécution, entre pas à pas ou continu.
Signaux d'entrée | - CmdSelMode
Signaux de sortie | - CmdMode
Signaux E/S | - NA

Fonction | FS2.2 | Navigation Menu
Description / rôle | Fonction qui sert à naviguer dans le menu.
Signaux d'entrée | - CmdNavMenu
Signaux de sortie | - CmdNav<0:2>
Signaux E/S | - NA

Fonction | FS2.3 | Programmation Etat Actuel
Description / rôle | Fonction qui permet de programmer l’état actuel de la table de transition.
Signaux d'entrée | - CmdProgEtatA
Signaux de sortie | - CmdEtatA<0:3>
Signaux E/S | - NA
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

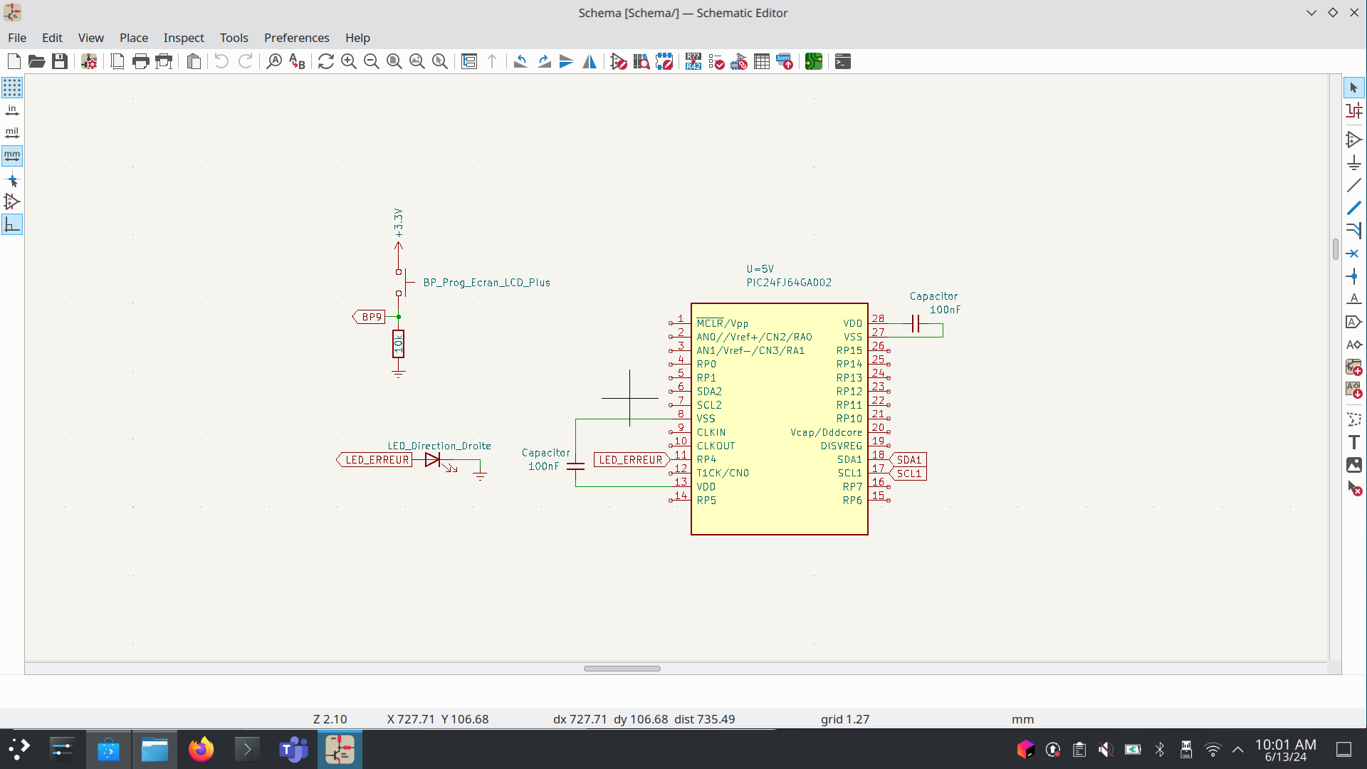
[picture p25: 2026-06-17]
Projet Elec - Machine de Turing/KiCad/Machine_de_turing/Image/Screenshot_20240613_100141.png

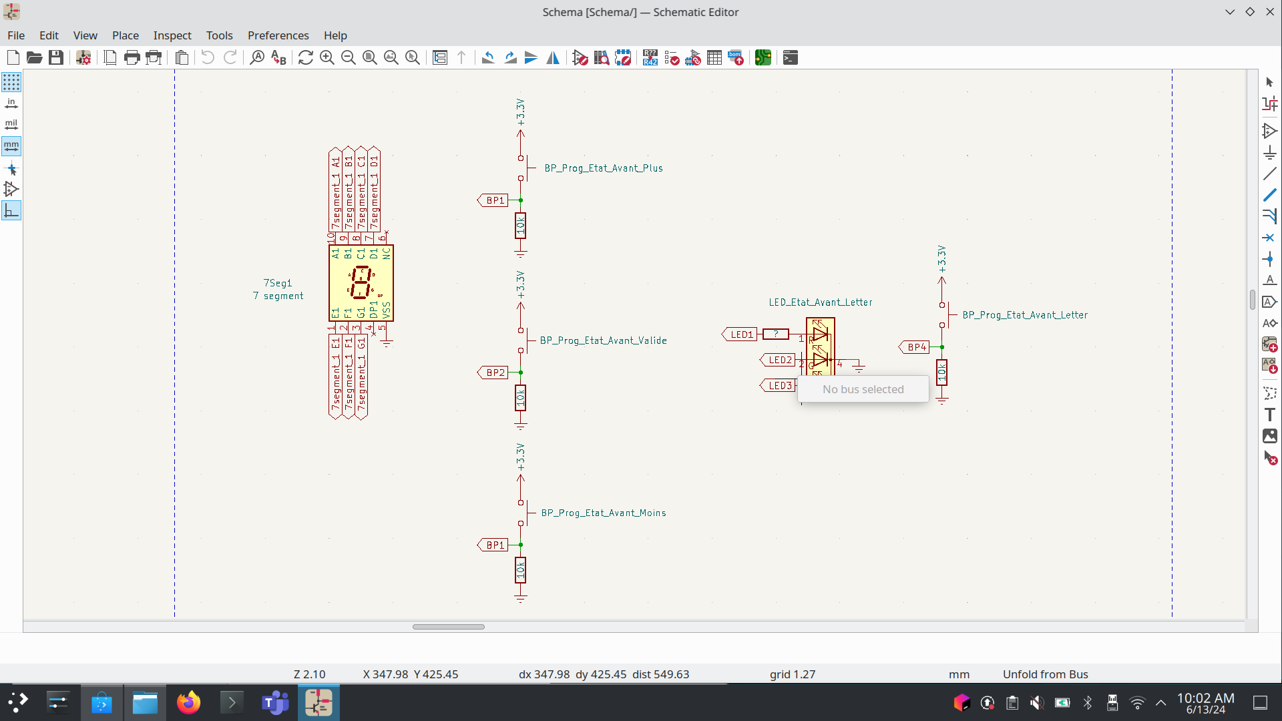
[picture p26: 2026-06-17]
Projet Elec - Machine de Turing/KiCad/Machine_de_turing/Image/Screenshot_20240613_100207.png

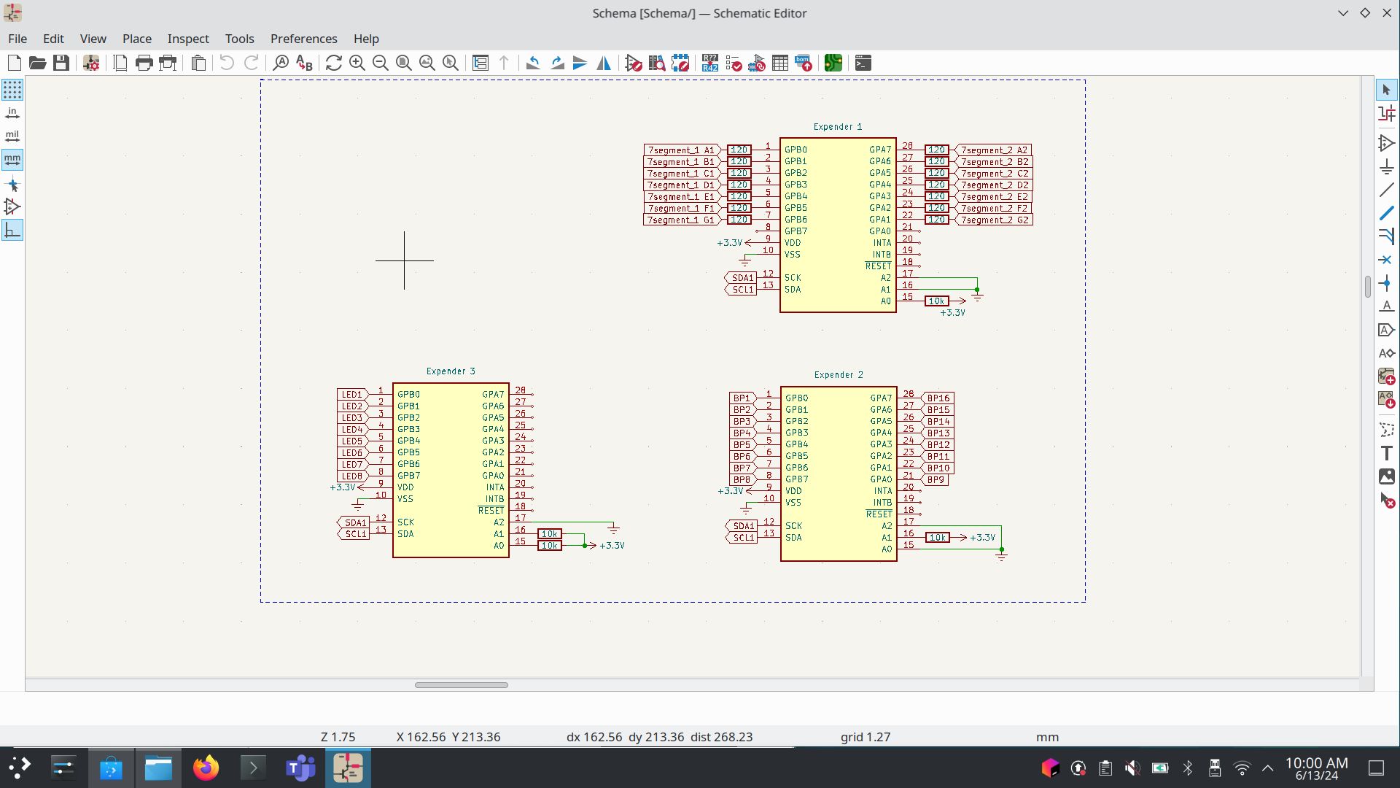
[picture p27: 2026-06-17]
Projet Elec - Machine de Turing/KiCad/Machine_de_turing/Image/Screenshot_20240613_100051.png

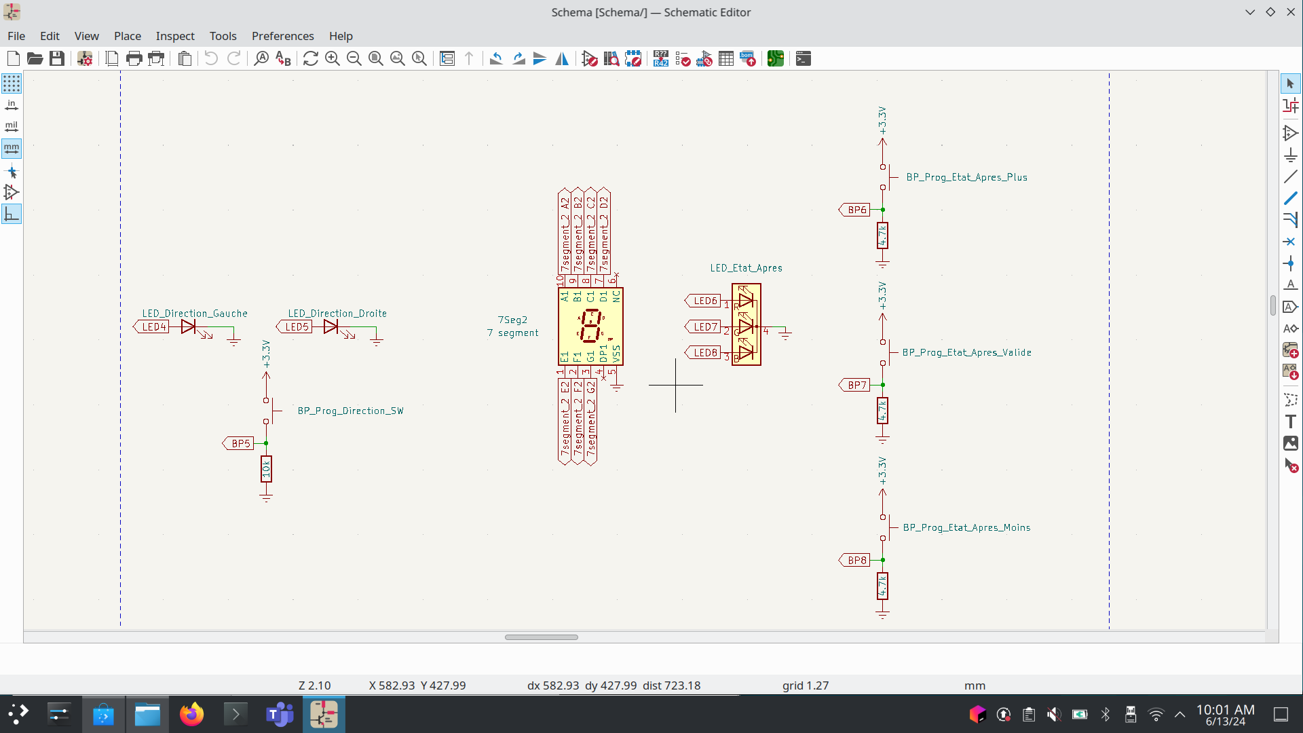
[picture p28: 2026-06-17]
Projet Elec - Machine de Turing/KiCad/Machine_de_turing/Image/Screenshot_20240613_100154.png

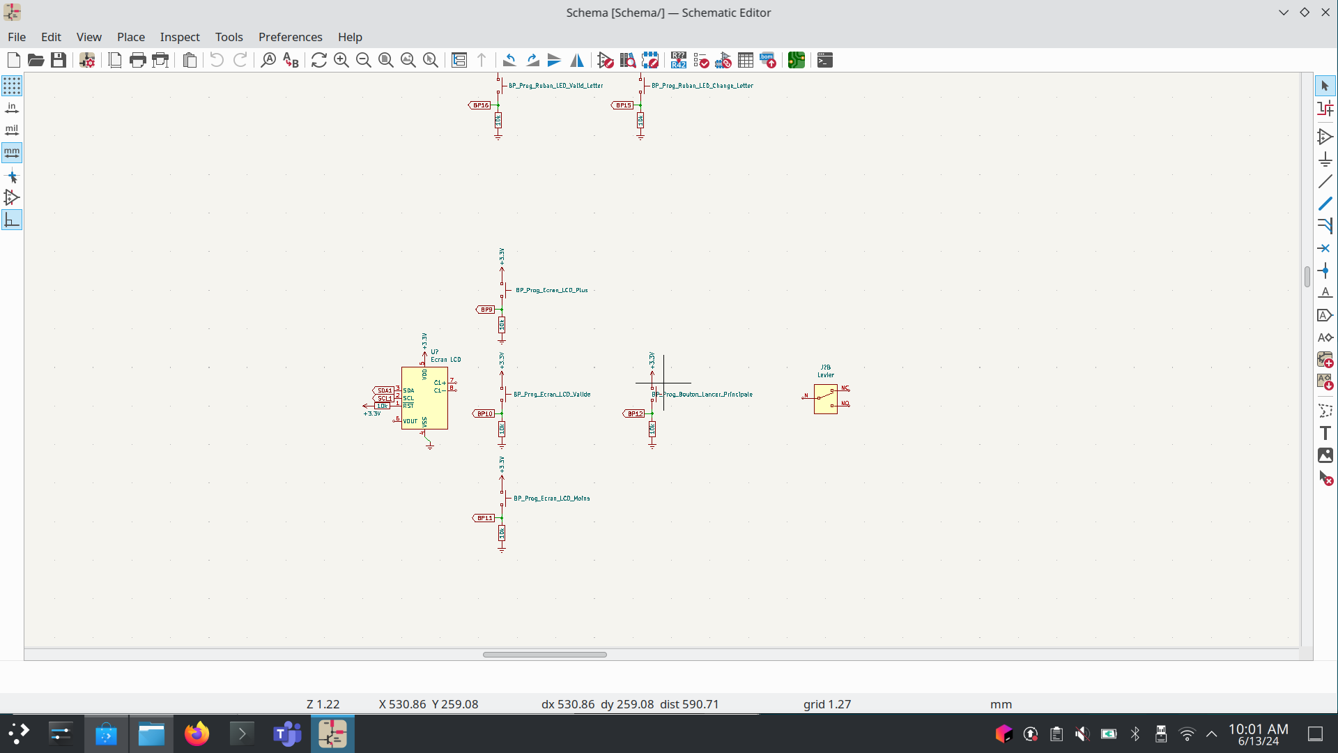
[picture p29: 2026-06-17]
Projet Elec - Machine de Turing/KiCad/Machine_de_turing/Image/Screenshot_20240613_100124.png

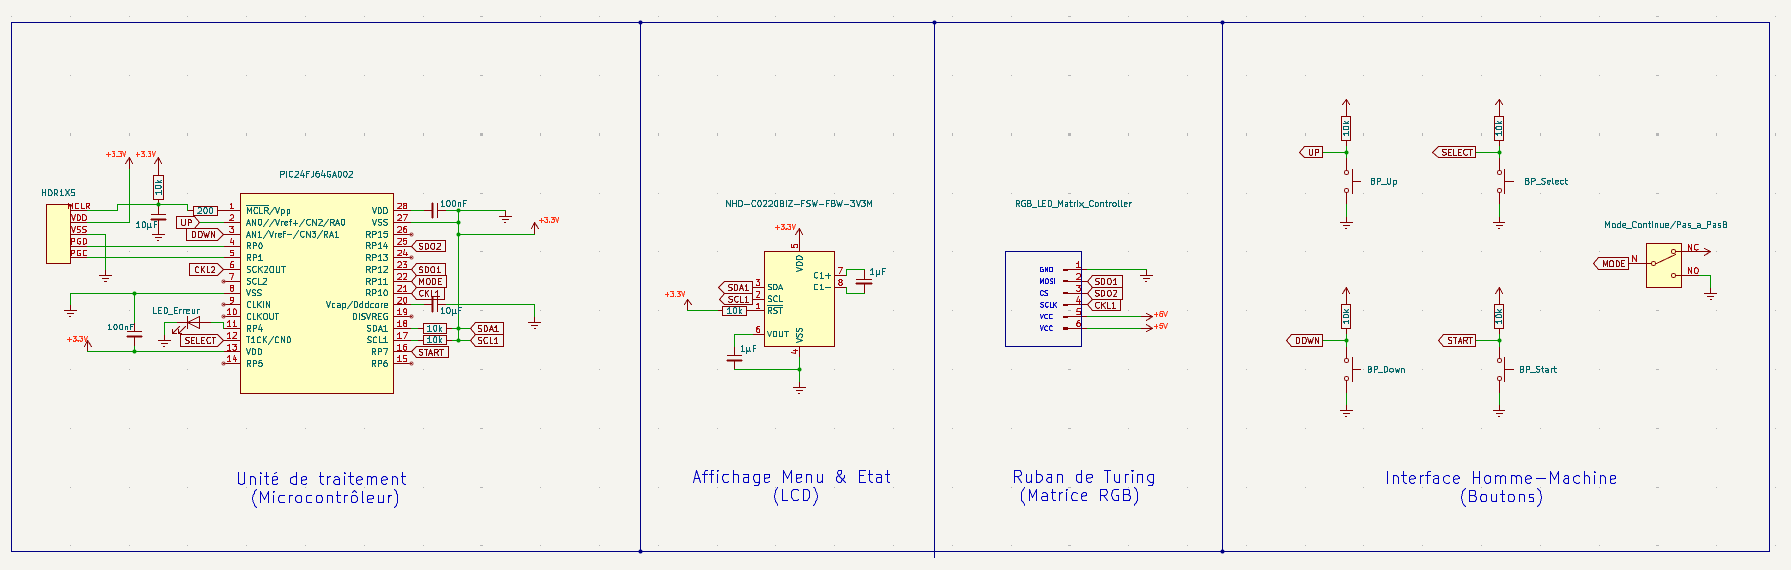
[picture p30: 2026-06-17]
Projet Elec - Machine de Turing/Schéma_élec/Schéma_élec_V1.png

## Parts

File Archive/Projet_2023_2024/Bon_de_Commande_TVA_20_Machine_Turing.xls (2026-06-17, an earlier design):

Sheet: Bon à remplir
Fournisseur | Nom | Mouser
 | Adresse
Etudiants | Promotion | ISIE 2023-2026 |  | Encadrant | Nom
 | Noms | BROUARD Romain | ALLEGRE--COMMINGES Clément |  | BOCQUILLON Ronan
Projet | Type | Projet elec
 | Identifiant (titre ou Id) | Machine de Turing
N° nom. | Références | Devis | Désignation produits, prestations |  | N°inventaire | Montant unitaire H.T. | Quantité | Montant H.T. | Montant T.V.A. | Montant T.T.C.
 | MC21605C6W-BNMLWI-V2 |  | Ecran LCD I2C |  |  | 14.80 € | 1 | 14.80 € | 2.96 € | 17.76 €
 | HDSP-7513 |  | Afficheur 7 segments |  |  | 3.45 € | 2 | 6.90 € | 1.38 € | 8.28 €
 | L-59EYC |  | LED RGB |  |  | 0.42 € | 2 | 0.84 € | 0.17 € | 1.01 €
 | MCP23017 |  | Expandeur IO/I2C |  |  | 2.08 € | 1 | 2.08 € | 0.42 € | 2.50 €
 | SK9822 |  | Ruban de leds RGB SPI |  |  | 19.98 € | 1 | 19.98 € | 4.00 € | 23.98 €
 | TLHK5100 |  | LEDS rouges |  |  | 0.47 € | 2 | 0.94 € | 0.19 € | 1.13 €
 | 2AS2T2A1M7RE |  | Interrupteur à bascule |  |  | 2.42 € | 2 | 4.84 € | 0.97 € | 5.81 €
 | ESE20C321 |  | Boutons poussoirs NO |  |  | 1.14 € | 14 | 15.96 € | 3.19 € | 19.15 €
 | BS17O |  | N-mos |  |  | 0.45 € | 2 | 0.90 € | 0.18 € | 1.08 €
 | MRS25000C8450FCT00 |  | Résistances 845 Ohms |  |  | 0.15 € | 7 | 1.05 € | 0.21 € | 1.26 €
 |  |  |  |  |  |  |  | 68.29 € | 13.66 € | 81.95 €
Date | 2024-06-13

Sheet: Fournisseurs
RS
Farnell
Digikey
Mouser
Gotronic
Lextronic
Conrad.pro
LDLC.Pro
Flash RC
Leroy Merlin

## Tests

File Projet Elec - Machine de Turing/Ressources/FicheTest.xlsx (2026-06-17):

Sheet: Fiche Test vierge
Système ou Objet Technique | Machine de Turing Électronique
Référence du Test
Objectifs du test | Valider la communication avec le microcontrôleur, l'alimentation des périphériques et l'acquisition des commandes IHM de base
Préparation du test
Matériel de mesure à mettre en œuvre | Matériel | Caractéristiques principales
 | Alimentation | Module d'alimentation stabilisé (réglé sur 3,3V et 5V)
 | Oscilloscope | X
 | Multimètre | Vérification de la continuité et de la tension sur la pin Vcap
 | GBF | X
 | Autre(s) | Sonde de programmation PICkit 4
Autres matériels à mettre en œuvre |  | X
Outillage spécifique |  | X
Besoins logiciels | MPLAB X
Description du test |  |  | Déroulement du test
Etat initial |  |  | Positionnement à l'état initial
Opérations à effectuer | Résultat(s) attendus | Remarques / Précisions | Résultat(s) obtenus | Opération Validée | Remarques / précisions
Connecter le PICkit 4 et alimenter la breadboard | Détection du PIC24FJ64GA002 par MPLAB X | Vérifier le condensateur de 10µF sur Vcap | PIC24FJ64GA002 reconnu | Validé | Programmation opérationnelle
Actionner les boutons poussoirs "UP" et "DOWN" | Allumage des LEDs ou changement d'état logiciel | Validation de l'entrée numérique | Les entrées sont bien détectées par le programme | Validé | Hardware validé pour ces deux pins
Envoyer une trame I2C vers l'afficheur LCD | Affichage du texte de bienvenue (Hello World) | Test de la communication bus I2C | L'écran reste inerte | Non Validé | Défaut au niveau du code ou LCD HS
Actionner les boutons "START" et "SELECT" | Lancement de la procédure de calcul (Addition) | Vérification du multiplexage des pins | Le programme lance bien la procédure de calcul | Validé
Piloter la matrice via le bus SPI | Allumage séquentiel des cases du ruban | Test de la gestion du ruban RGB | La matrice est piloté via le bus SPI | Validé
Basculer le commutateur entre les deux modes | Changement d'état détecté par le microcontrôleur | Vérification du signal sur la pin RP11 | Câblage OK, signal stable sur l'entrée | Non Validé | Test logiciel à réaliser pour confirmer la bascule Continu/Pas-à-pas
Forcer une condition d'erreur logicielle | Allumage de la LED rouge de diagnostic | Test du circuit de signalisation d'erreur | La LED s'allume correctement via le code | Validé | Hardware opérationnel pour le retour d'erreur

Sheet: Sources Data
Validé
Non Validé

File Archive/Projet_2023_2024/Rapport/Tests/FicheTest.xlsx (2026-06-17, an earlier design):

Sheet: Fiche Test vierge
Système ou Objet Technique | Machine de Turing
Référence du Test
Objectifs du test | Confirmer fonctionnement du MCP23017
Préparation du test
Matériel de mesure à mettre en œuvre | Matériel | Caractéristiques principales
 | Alimentation | 3,3V
 | Oscilloscope
 | Multimètre | Voltmètre
 | GBF
 | Autre(s)
Autres matériels à mettre en œuvre | PIC24FJ64GA002, MCP23017, câbles de branchements
Outillage spécifique
Besoins logiciels
Schémas
Description du test |  |  | Déroulement du test
Etat initial | PIC24 chargé, Platine Breadboard Cablée: MCP23017 branché au PIC24 : pin 12 sur pin 17, pin 13 sur pin 18, pin 10 à la masse pin 9 sur 3,3V |  | Positionnement à l'état initial
Opérations à effectuer | Résultat(s) attendus | Remarques / Précisions | Résultat(s) obtenus | Opération Validée | Remarques / précisions
Mesurer une tension sur la broche 1 du MCP23017 | 3,3V sur le multimètre | Led d'alim allumée |  | Non Validé
 |  |  |  | Non Validé
 |  |  |  | Non Validé
 |  |  |  | Non Validé
 |  |  |  | Non Validé
 |  |  |  | Non Validé
 |  |  |  | Non Validé
 |  |  |  | Non Validé
 |  |  |  | Non Validé
 |  |  |  | Non Validé

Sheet: Sources Data
Validé
Non Validé

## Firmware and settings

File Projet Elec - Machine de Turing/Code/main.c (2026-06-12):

#include "xc.h"

// CONFIG1
#pragma config WDTPS = PS32768   // Watchdog Timer Postscaler (1:32,768)
#pragma config FWPSA = PR128     // WDT Prescaler (Prescaler ratio of 1:128)
#pragma config WINDIS = ON       // Watchdog Timer Window (Standard Watchdog Timer enabled,(Windowed-mode is disabled))
#pragma config FWDTEN = OFF      // Watchdog Timer Enable (Watchdog Timer is disabled)
#pragma config ICS = PGx2        // Comm Channel Select (Emulator/debugger uses EMUC2/EMUD2)
#pragma config GWRP = OFF        // General Code Segment Write Protect (Writes to program memory are allowed)
#pragma config GCP = OFF         // General Code Segment Code Protect (Code protection is disabled)
#pragma config JTAGEN = OFF      // JTAG Port Enable (JTAG port is disabled)      
// CONFIG2
#pragma config POSCMOD = HS      // Primary Oscillator Select (Primary oscillator disabled)
#pragma config OSCIOFNC = ON     // Primary Oscillator Output Function (OSC2/CLKO/RC15 functions as CLKO (FOSC/2))
#pragma config FCKSM = CSECMD    // Clock Switching and Monitor (Clock switching and Fail-Safe Clock Monitor are enable)
#pragma config FNOSC = FRCDIV    // Oscillator Select (Fast RC Oscillator with Postscaler (FRCDIV))
#pragma config IESO = OFF        // Internal External Switch Over Mode (IESO mode (Two-Speed Start-up) enabled)

#include "lib_turing.h"

int main(void) {
    Turing_Init();
    
    while(1) {
        Turing_Task();
    }
    
    return 0;
}

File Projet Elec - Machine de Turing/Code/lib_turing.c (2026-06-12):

#include "lib_turing.h"

// ==============================================================================
// TEST NUMERO 7 : MACHINE DE TURING COMPLETE (Saisie + Algorithme + Appui Long)
// ==============================================================================
#if (CURRENT_TEST == TEST_MACHINE_TURING)

#define TAILLE_ALPHABET 3

typedef enum { rien = 0, gauche = -1, droite = 1 } Deplacement;

struct action {
  int nv_char;
  Deplacement dep;
  int nv_etat;
};
typedef struct action Action;

struct etat {
    int final;
    Action transition[TAILLE_ALPHABET];
};
typedef struct etat Etat;

void action_create(Action *A, int a, Deplacement dep, int nv_etat) {
    if((a < TAILLE_ALPHABET) && (a >= 0)) {
        A->nv_char = a;
        A->dep = dep;
        A->nv_etat = nv_etat;
    }
}

// Variables globales du Test 7
Etat Etats_Turing[7];
int bande_turing[8] = {0,0,0,0,0,0,0,0}; // 0=Vide, 1=Vert(Bit 1), 2=Rouge(Bit 0)
int position_curseur = 0; 

// --- Config SPI ---
void SPI_Init(void) {
    SPI1STAT = 0; 
    TRISBbits.TRISB12 = 0; // MOSI 
    TRISBbits.TRISB13 = 0; // SCK 
    
    __builtin_write_OSCCONL(OSCCON & 0xbf); 
    RPOR6bits.RP12R = 7; 
    RPOR6bits.RP13R = 8; 
    __builtin_write_OSCCONL(OSCCON | 0x40); 
    
    SPI1CON1bits.MSTEN = 1;   
    SPI1CON1bits.MODE16 = 0;  
    SPI1CON1bits.CKP = 0;     
    SPI1CON1bits.CKE = 1;     
    SPI1CON1bits.SMP = 0;     
    SPI1CON1bits.PPRE = 0b00;  
    SPI1CON1bits.SPRE = 0b111; 
    
    SPI1STATbits.SPIEN = 1;   
}

void SPI_Write(uint8_t data) {
    uint8_t donnee_recue;
    SPI1BUF = data;                     
    while(SPI1STATbits.SPIRBF == 0);    
    donnee_recue = SPI1BUF;             
}

// --- Dessin de l'ecran ---
void Matrix_Draw(int *bande, int curseur) {
    int i;
    MATRICE_CS_LAT = 0; 
    __delay_ms(1);
    SPI_Write(0x26);    
    __delay_ms(1);
    MATRICE_CS_LAT = 1; 
    
    __delay_ms(2); 
    MATRICE_CS_LAT = 0; 
    __delay_ms(1);      
    
    // Ligne 1 : Lecture du tableau de Turing
    for(i = 0; i < 8; i++) {
        if(bande[i] == 0)      SPI_Write(COULEUR_NOIR);
        else if(bande[i] == 1) SPI_Write(COULEUR_VERT);
        else if(bande[i] == 2) SPI_Write(COULEUR_ROUGE);
    }
    
    // Lignes 2 a 7 : Vides
    for(i = 8; i < 56; i++) {
        SPI_Write(COULEUR_NOIR); 
    }
    
    // Ligne 8 : Tete de lecture (Curseur Bleu)
    for(i = 56; i < 64; i++) {
        if((i - 56) == curseur) {
            SPI_Write(COULEUR_BLEU);
        } else {
            SPI_Write(COULEUR_NOIR);
        }
    }
    __delay_ms(1);      
    MATRICE_CS_LAT = 1; 
}

// ------- L'Algorithme d'addition ------
void Configurer_Algorithme_Addition(void) {
    
    // ETAT 0 
    Etats_Turing[0].final=0;
    action_create(&Etats_Turing[0].transition[2], 1, gauche, 1);     
    action_create(&Etats_Turing[0].transition[1], 2, gauche, 0); 
    action_create(&Etats_Turing[0].transition[0], 0, rien, 0);   

    // ETAT 1 
    Etats_Turing[1].final=0;
    action_create(&Etats_Turing[1].transition[2], 2, gauche, 1);   
    action_create(&Etats_Turing[1].transition[1], 1, gauche, 1); 
    action_create(&Etats_Turing[1].transition[0], 0, gauche, 2); 

    // ETAT 2 
    Etats_Turing[2].final=0;
    action_create(&Etats_Turing[2].transition[2], 1, droite, 3); 
    action_create(&Etats_Turing[2].transition[1], 2, gauche, 2); 
    action_create(&Etats_Turing[2].transition[0], 1, droite, 3); 

    // ETAT 3 
    Etats_Turing[3].final=0;
    action_create(&Etats_Turing[3].transition[2], 2, droite, 3);     
    action_create(&Etats_Turing[3].transition[1], 1, droite, 3); 
    action_create(&Etats_Turing[3].transition[0], 0, droite, 4); 

    // ETAT 4 
    Etats_Turing[4].final=0;
    action_create(&Etats_Turing[4].transition[2], 2, droite, 5);     
    action_create(&Etats_Turing[4].transition[1], 1, droite, 4); 
    action_create(&Etats_Turing[4].transition[0], 0, gauche, 0); 

    // ETAT 5 
    Etats_Turing[5].final=0;
    action_create(&Etats_Turing[5].transition[2], 2, droite, 5);    
    action_create(&Etats_Turing[5].transition[1], 1, droite, 5); 
    action_create(&Etats_Turing[5].transition[0], 0, gauche, 0); 
    
    // ETAT 6 
    Etats_Turing[6].final=1;
}

// --- Moteur de calcul ---
void Lancer_Calcul_Turing(void) {
    int etat_actuel = 0;
    int symbole_lu = 0;
    
    int a = 7;
    while((a >= 0) && (bande_turing[a] == 0)) {
        a--;
    }
    position_curseur = a; 
    
    while(Etats_Turing[etat_actuel].final != 1) {
        symbole_lu = bande_turing[position_curseur];
        
        bande_turing[position_curseur] = Etats_Turing[etat_actuel].transition[symbole_lu].nv_char;
        position_curseur += Etats_Turing[etat_actuel].transition[symbole_lu].dep;
        etat_actuel = Etats_Turing[etat_actuel].transition[symbole_lu].nv_etat;
        
        if(position_curseur < 0) position_curseur = 0;
        if(position_curseur > 7) position_curseur = 7;
        
        Matrix_Draw(bande_turing, position_curseur);
        __delay_ms(1500); 
    }
    
    Matrix_Draw(bande_turing, -1); 
    while(1); 
}

void Turing_Init(void) {
    AD1PCFG = 0xFFFF; 
    
    MATRICE_CS_TRIS = 0; 
    MATRICE_CS_LAT = 1; 
    SPI_Init(); 
    
    TRISAbits.TRISA0 = 1; 
    TRISAbits.TRISA1 = 1; 
    TRISAbits.TRISA4 = 1; 
    
    CNPU1bits.CN2PUE = 1;  
    CNPU1bits.CN3PUE = 1;  
    CNPU1bits.CN0PUE = 1;  
    
    Configurer_Algorithme_Addition();
    
    __delay_ms(3000); 
    Matrix_Draw(bande_turing, position_curseur);
}
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

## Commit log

2026-06-12 Enhance README with project details and features
    Added detailed project description and features for the Electronic Turing Machine Prototype, including hardware architecture, code structure, and compilation instructions.
2026-06-12 Change project title in README.md
    Updated project title from 'Electronic Turing Machine Prototype' to 'Machine de Turing'.
